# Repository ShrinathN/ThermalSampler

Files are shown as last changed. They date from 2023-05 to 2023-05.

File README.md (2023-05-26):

# ThermalSampler

Wireless thermal logger. Intended use is to help in thermally modelling a room.

Sensor nodes made using an STM32G0 MCU and connectivity options include

* nRF24L01+
* RFM95W/CW/TW
* RFM96W/TW

Sleep current is ~2uA

Aggregator is a simple ESP32 based dev board connected to nRF24L01+ (PA breakout board) in my case.

# Fully assembled

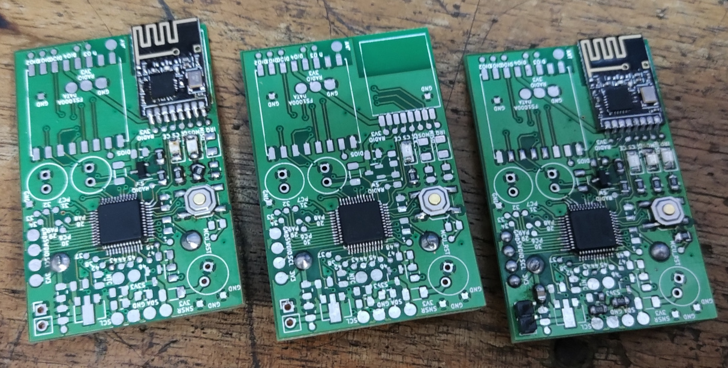
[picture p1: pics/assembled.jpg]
Assembled 1

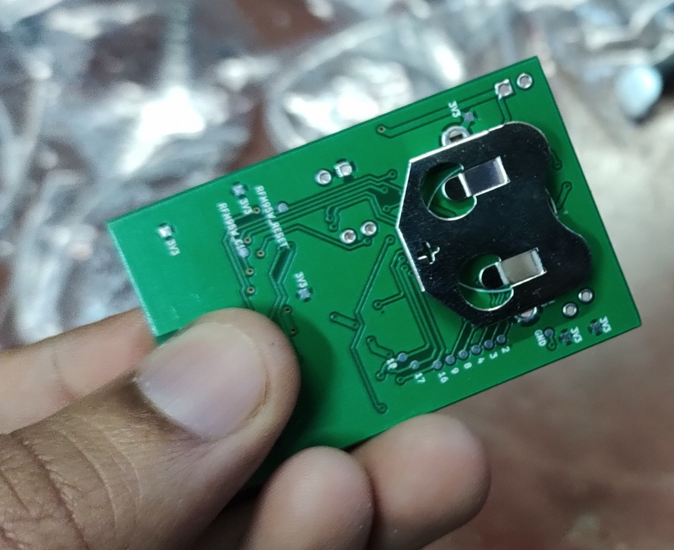
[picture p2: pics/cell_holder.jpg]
Assembled 2

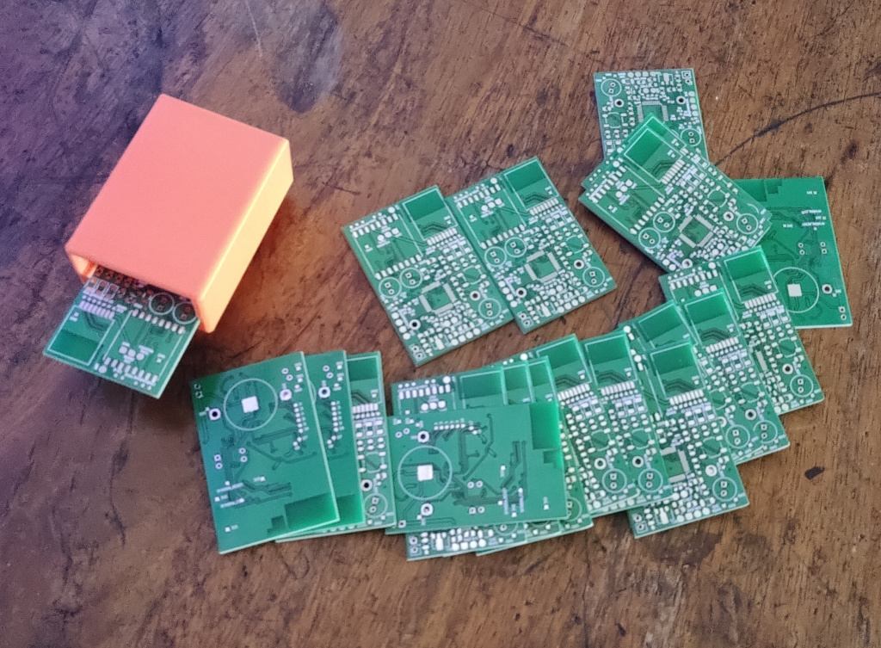
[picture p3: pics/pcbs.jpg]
Assembled 3

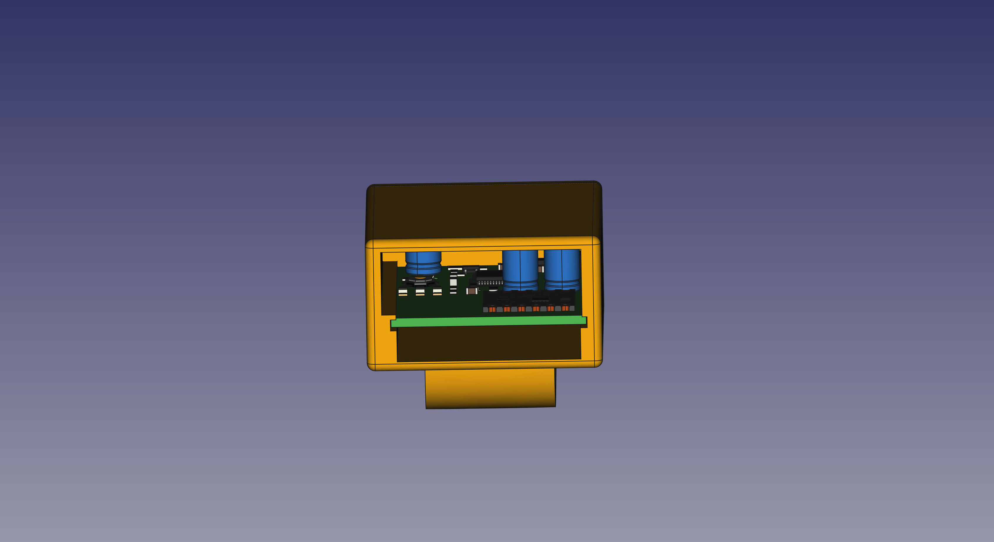
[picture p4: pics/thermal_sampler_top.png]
Assembled 4


# PCB

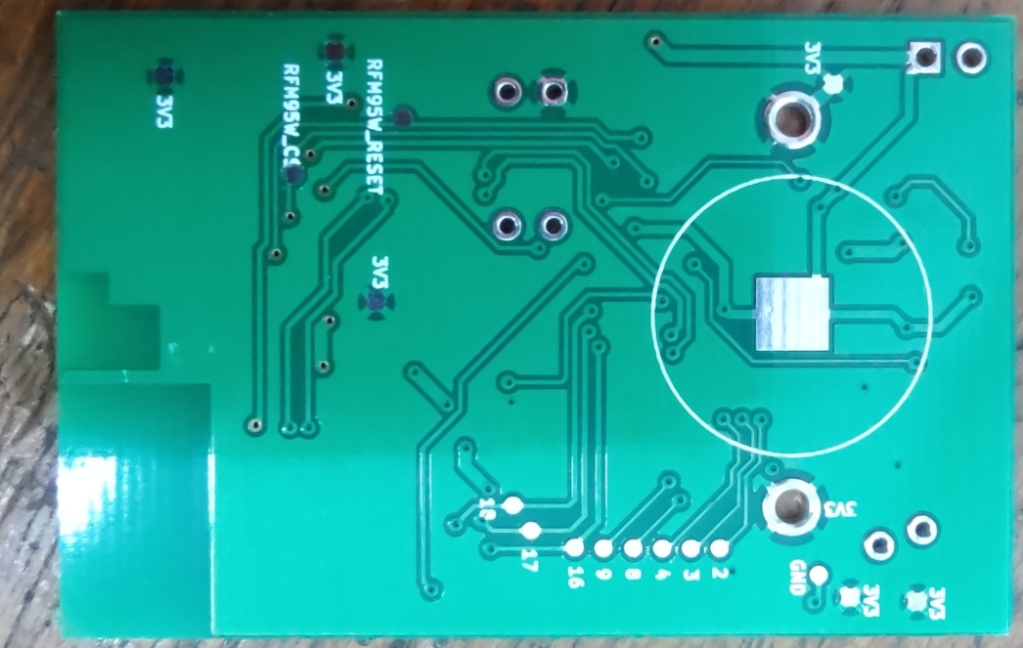
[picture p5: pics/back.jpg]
Front

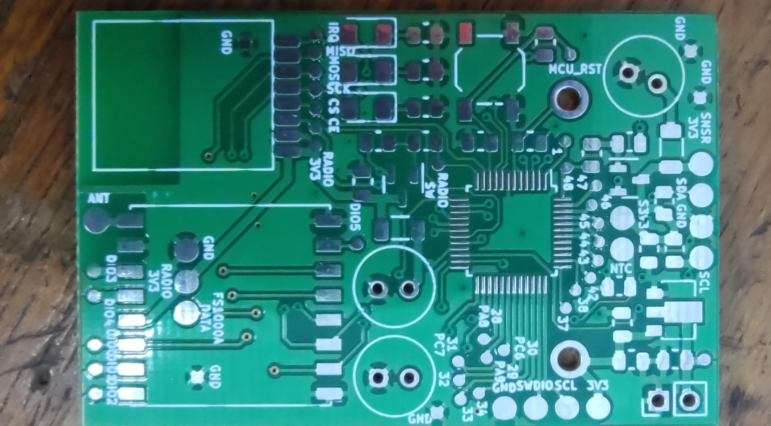
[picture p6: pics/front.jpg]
Back

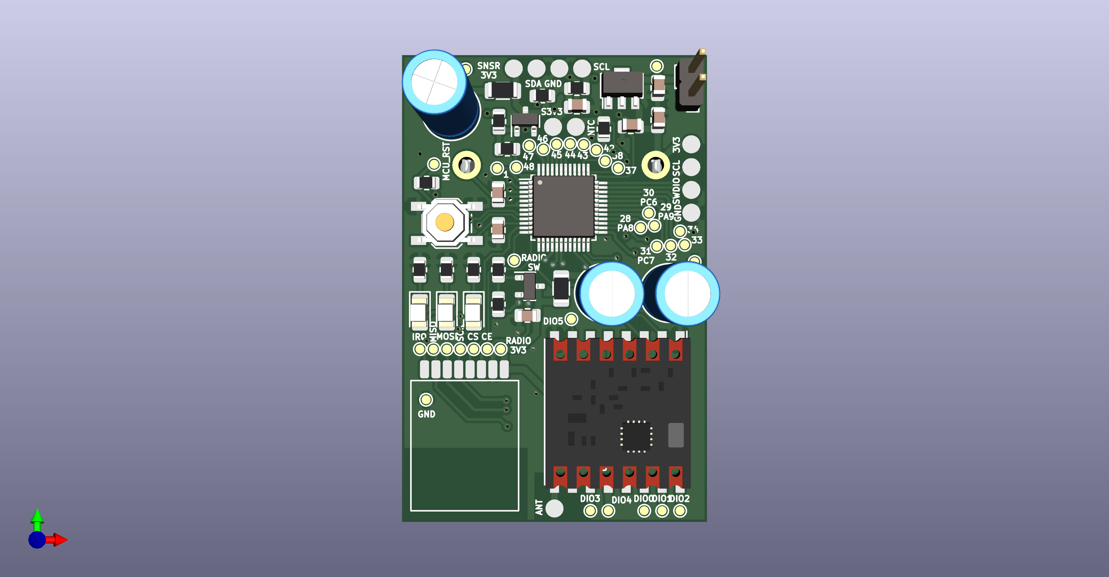
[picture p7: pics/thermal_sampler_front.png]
FrontRender

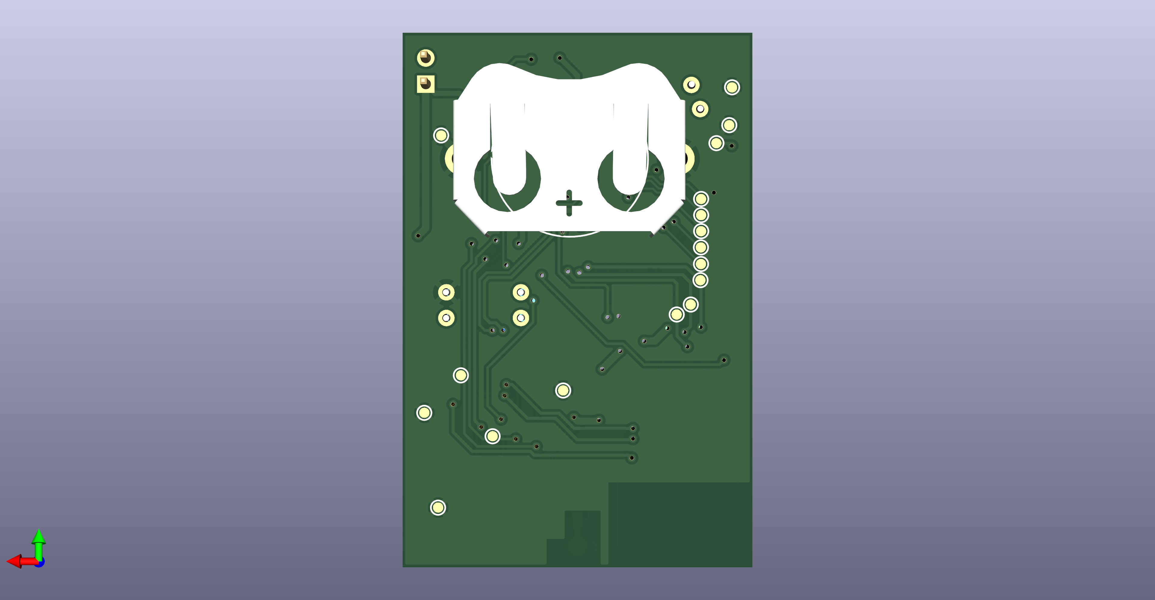
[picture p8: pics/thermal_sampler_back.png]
BackRender


# Enclosure

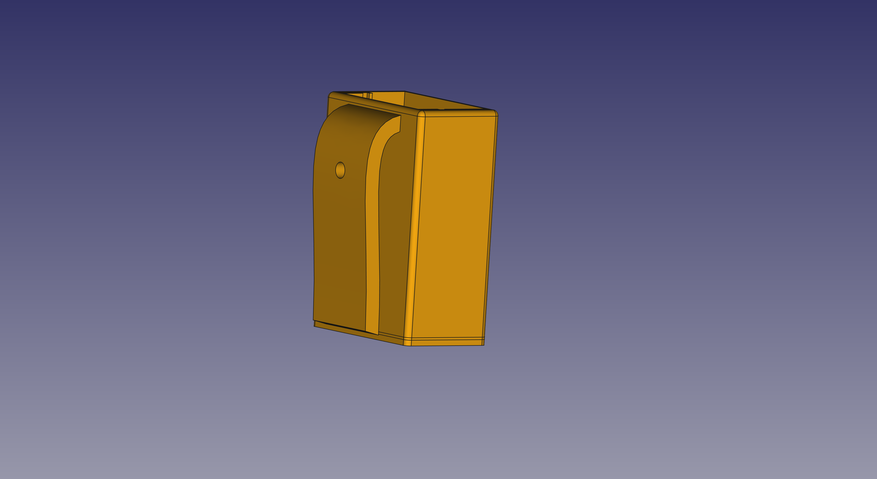
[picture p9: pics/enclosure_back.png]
Perspective 1

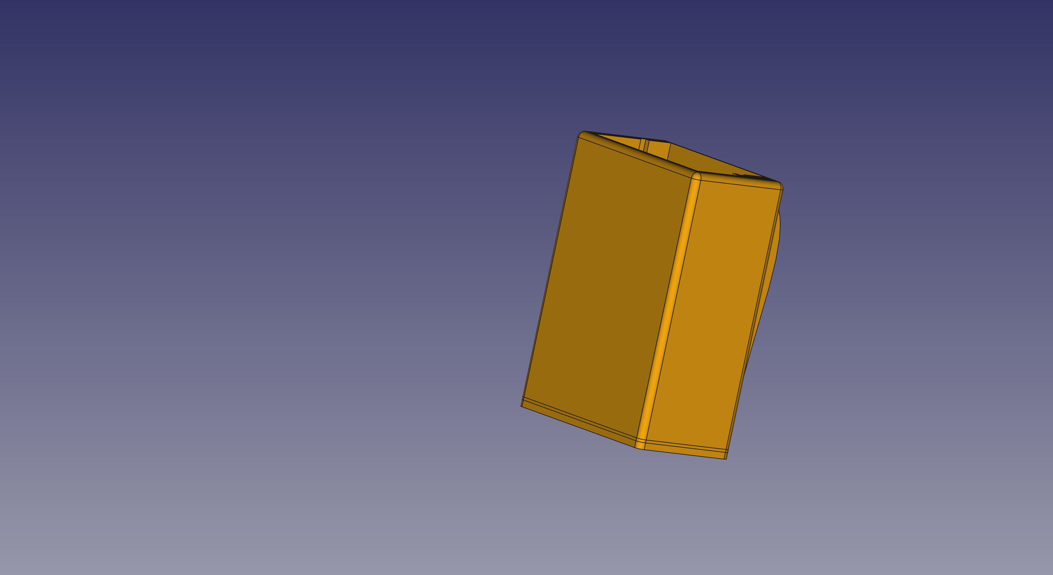
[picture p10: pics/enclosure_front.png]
Perspective 2

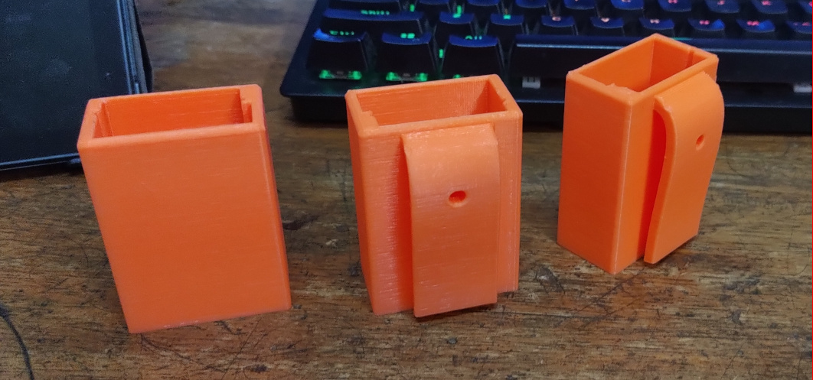
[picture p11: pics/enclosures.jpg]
Perspective 3


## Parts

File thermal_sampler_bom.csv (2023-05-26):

Item | Qty | Reference(s) | Value | LibPart | Footprint | Datasheet | For 5 boards
1 | 5 | C1, C2, C3, C7, C9 | 10uF | Device:C | Capacitor_SMD:C_0805_2012Metric | ~ | 25
2 | 3 | C4, C8, C10 | 220uF | Device:C | Capacitor_THT:C_Radial_D6.3mm_H11.0mm_P2.50mm | ~ | 15
3 | 2 | C5, C6 | 100nF | Device:C | Capacitor_SMD:C_0805_2012Metric | ~ | 10
4 | 3 | D1, D2, D3 | LED | Device:LED | LED_SMD:LED_1206_3216Metric | ~ | 15
5 | 1 | J1 | CR2032 | Connector_Generic:Conn_01x02 | CR2032_THT:CR2032_THT | ~ | 5
6 | 1 | J2 | power_connector | Connector_Generic:Conn_01x02 | Connector_PinHeader_2.54mm:PinHeader_1x02_P2.54mm_Vertical | ~ | 5
7 | 1 | J3 | swd_header | Connector_Generic:Conn_01x04 | smd_footprint:Conn_01x04 | ~ | 5
8 | 1 | J4 | RFM95W_Antenna | Connector_Generic:Conn_01x01 | smd_footprint:Conn_01x01 | ~ | 5
9 | 1 | J5 | FS1000A | Connector_Generic:Conn_01x03 | smd_footprint:Conn_01x03 | ~ | 5
10 | 1 | J6 | ZS05 | Connector_Generic:Conn_01x04 | smd_footprint:Conn_01x04 | ~ | 5
11 | 1 | J7 | thermistor_connector | Connector_Generic:Conn_01x02 | smd_footprint:Conn_01x02 | ~ | 5
12 | 2 | Q1, Q2 | CJ3401 | Device:Q_PMOS_GSD | Package_TO_SOT_SMD:SOT-23 | ~ | 10
13 | 3 | R1, R6, R11 | 1Meg | Device:R | Resistor_SMD:R_0805_2012Metric | ~ | 15
14 | 3 | R2, R3, R4 | 1k | Device:R | Resistor_SMD:R_0805_2012Metric | ~ | 15
15 | 2 | R5, R10 | 22R | Device:R | Resistor_SMD:R_0805_2012Metric | ~ | 10
16 | 2 | R7, R12 | 2R | Device:R | Resistor_SMD:R_1206_3216Metric | ~ | 10
17 | 2 | R8, R9 | 4k7 | Device:R | Resistor_SMD:R_0805_2012Metric | ~ | 10
18 | 1 | R13 | 100k | Device:R | Resistor_SMD:R_0805_2012Metric | ~ | 5
19 | 1 | SW1 | rst_switch | Switch:SW_Push | Button_Switch_SMD:SW_SPST_TL3342 | ~ | 5
20 | 1 | U1 | HT7333 | HT7333:HT7333 | Package_TO_SOT_SMD:SOT-89-3 | https://datasheet.lcsc.com/szlcsc/Holtek-Semicon-HT7333-A_C21583.pdf | 5
21 | 1 | U2 | STM32G030C8T6 | STM32G030C8T6:STM32G030C8T6 | Package_QFP:LQFP-48_7x7mm_P0.5mm |  | 5
22 | 1 | U3 | nRF24L01_SMD | nrf24l01_smd:nRF24L01_SMD | nRF24L01_SMD:nRF24L01_SMD |  | 5
23 | 1 | U4 | RFM95W-868S2 | RF_Module:RFM95W-868S2 | RF_Module:HOPERF_RFM9XW_SMD | https://www.hoperf.com/data/upload/portal/20181127/5bfcbea20e9ef.pdf | 5

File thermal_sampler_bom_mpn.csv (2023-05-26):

S.No | Quantity | Designator | Description (VALUE) | Manufacturing Part No
1 | 5 | C1, C2, C3, C7, C9 | 10uF | CL21A106KPFNNNE
2 | 3 | C4, C8, C10 | 220uF | UWT1H221MNL1GS
3 | 2 | C5, C6 | 100nF | 0805B104K500NT
4 | 3 | D1, D2, D3 | LED | SZYY1206R
5 | 1 | J1 | CR2032 | MY-2032-08
6 | 1 | J2 | power_connector | RE-H022TD-1190(LF)(SN)
7 | 1 | J6 | ZS05 | DHT11
8 | 2 | Q1, Q2 | CJ3401 | CJ3401
9 | 3 | R1, R6, R11 | 1Meg | 0805W8F1004T5E
10 | 3 | R2, R3, R4 | 1k | RC0805FR-071KL
11 | 2 | R5, R10 | 22R | RC0805FR-0722RL
12 | 2 | R7, R12 | 2R | FRC0805J2R0TS
13 | 2 | R8, R9 | 4k7 | RS-05K472JT
14 | 1 | R13 | 100k | 0805W8F1003T5E
15 | 1 | SW1 | rst_switch | TS-1187A-B-A-B
16 | 1 | U1 | HT7333 | HT7333-A
17 | 1 | U2 | STM32G030C8T6 | STM32G030C8T6
18 | 1 | U4 | RFM95W-868S2 | DL-RFM95-868M

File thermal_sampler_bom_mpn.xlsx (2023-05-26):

S.No | Quantity | Designator | Description (VALUE) | Manufacturing Part No
1 | 5 | C1, C2, C3, C7, C9 | 10uF | C0805C106K8PAC7800
2 | 3 | C4, C8, C10 | 220uF | RL81C221MDN1KX
3 | 2 | C5, C6 | 100nF | 0805B104K101CC
4 | 3 | D1, D2, D3 | LED | LTST-C150KGKT
5 | 1 | J1 | CR2032 | 3035
6 | 1 | J2 | power_connector | 68000-102HLF
7 | 1 | J6 | ZS05 | 1528-5183-ND
8 | 2 | Q1, Q2 | CJ3401 | SSM3J328R,LF
9 | 3 | R1, R6, R11 | 1Meg | RC0805FR-071ML
10 | 3 | R2, R3, R4 | 1k | RC0805FR-071KL
11 | 2 | R5, R10 | 22R | RMCF0805JT22R0
12 | 2 | R7, R12 | 2R | RC0805FR-072RL
13 | 2 | R8, R9 | 4k7 | RMCF0805JT4K70
14 | 1 | R13 | 100k | RC0805FR-07100KL
15 | 1 | SW1 | rst_switch | PTS526 SK15 SMTR2 LFS
16 | 1 | U1 | HT7333 | HT7333-A
17 | 1 | U2 | STM32G030C8T6 | STM32G030C8T6
18 | 1 | U4 | RFM95W-868S2 | RFM95W-868S2

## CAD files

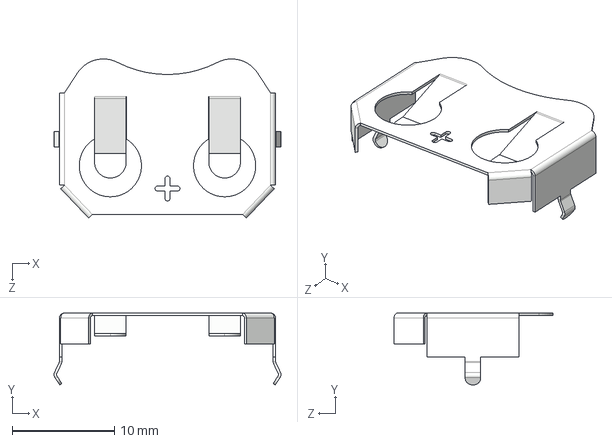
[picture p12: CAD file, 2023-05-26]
Custom Parts/3D Models/keystone-PN3035.STEP
22.2 x 7.04 x 15.6 mm

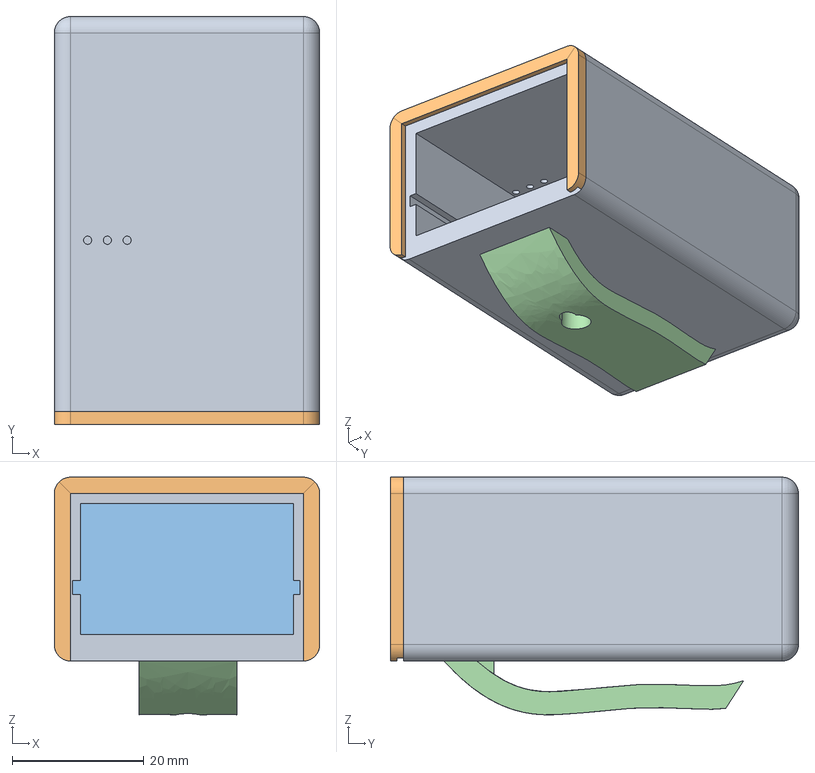
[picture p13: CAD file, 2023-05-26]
Enclosures/closed/Unnamed-Enclosure12.step
40.3 x 62.0 x 36.1 mm
MainBody
Top Rail
Back Close
Clip

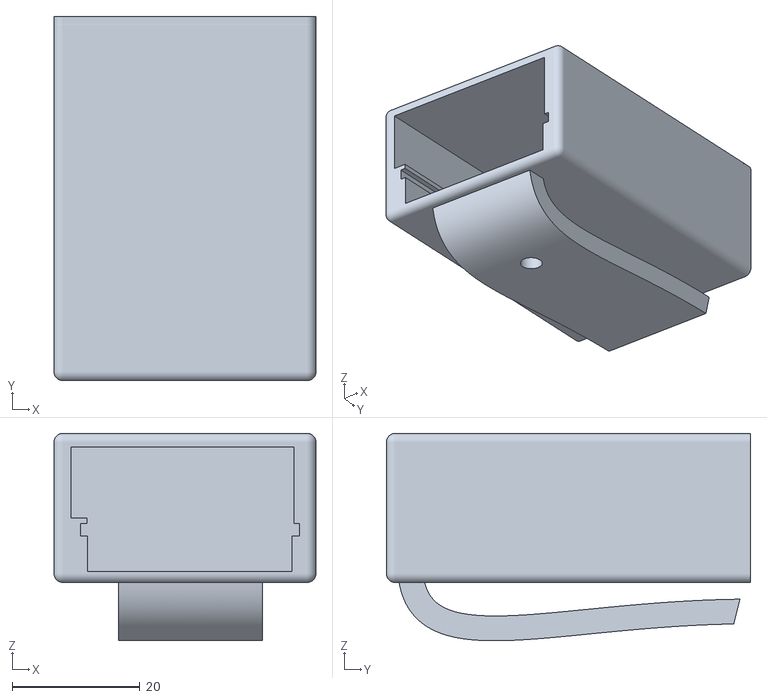
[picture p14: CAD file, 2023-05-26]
Enclosures/open_top/dabba2.stl
41.0 x 57.0 x 32.5

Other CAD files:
Enclosures/closed/dabba-Enclosure.step
Enclosures/open_top/dabba.FCStd
Enclosures/closed/enclosure_closed.stl
Enclosures/closed/dabba.FCStd
Enclosures/closed/Unnamed-Enclosure132.step
Enclosures/closed/Unnamed-Enclosure1.step
Enclosures/closed/Unnamed-Enclosure1.stl
Enclosures/open_top/dabba.stl

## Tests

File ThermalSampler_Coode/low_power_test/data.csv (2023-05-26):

 | id | temp | hum
0 | 0 | 30 | 27
1 | 1 | 30 | 27
2 | 2 | 30 | 27
3 | 3 | 30 | 27
4 | 4 | 30 | 27
5 | 5 | 30 | 27
6 | 6 | 30 | 27
7 | 7 | 30 | 27
8 | 8 | 30 | 27
9 | 9 | 30 | 27
10 | 10 | 30 | 27
11 | 11 | 30 | 27
12 | 12 | 30 | 27
13 | 13 | 30 | 27
14 | 14 | 30 | 27
15 | 15 | 30 | 27
16 | 16 | 30 | 27
17 | 17 | 30 | 27
18 | 18 | 30 | 27
19 | 19 | 30 | 27
20 | 20 | 30 | 28
21 | 21 | 30 | 28
22 | 22 | 30 | 28
23 | 23 | 30 | 28
24 | 24 | 30 | 28
25 | 25 | 30 | 28
26 | 26 | 29 | 28
27 | 27 | 30 | 29
28 | 28 | 29 | 29
29 | 29 | 29 | 29
30 | 30 | 29 | 29
31 | 31 | 29 | 29
32 | 32 | 29 | 29
33 | 33 | 29 | 30
34 | 34 | 29 | 30
35 | 35 | 29 | 30
36 | 36 | 29 | 30
37 | 37 | 29 | 31
38 | 38 | 29 | 31
39 | 39 | 29 | 31
40 | 40 | 29 | 32
41 | 41 | 29 | 32
42 | 42 | 29 | 32
43 | 43 | 29 | 33
44 | 44 | 29 | 33
45 | 45 | 29 | 33
46 | 46 | 29 | 33
47 | 47 | 29 | 34
48 | 48 | 29 | 34
49 | 49 | 29 | 34
50 | 50 | 28 | 35
51 | 51 | 28 | 35
52 | 52 | 29 | 35
53 | 53 | 28 | 35
54 | 54 | 28 | 36
55 | 55 | 28 | 36
56 | 56 | 28 | 36
57 | 57 | 28 | 37
58 | 58 | 28 | 37
59 | 59 | 28 | 37
60 | 60 | 28 | 38
61 | 61 | 28 | 38
62 | 62 | 28 | 38
63 | 63 | 28 | 38
64 | 64 | 28 | 39
65 | 65 | 28 | 39
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

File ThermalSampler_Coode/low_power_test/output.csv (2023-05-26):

 | id | temperature | humidity
0 | 230 | 30 | 27
1 | 231 | 30 | 27
2 | 232 | 30 | 27
3 | 0 | 30 | 27
4 | 1 | 30 | 27
5 | 2 | 30 | 27
6 | 3 | 30 | 27
7 | 4 | 30 | 27
8 | 5 | 30 | 27
9 | 6 | 30 | 27
10 | 7 | 30 | 27
11 | 8 | 30 | 27
12 | 9 | 30 | 27
13 | 10 | 30 | 27
14 | 11 | 30 | 27
15 | 12 | 30 | 27
16 | 13 | 30 | 27
17 | 14 | 30 | 27
18 | 15 | 30 | 27
19 | 16 | 30 | 27
20 | 17 | 30 | 27
21 | 18 | 30 | 27
22 | 19 | 30 | 27
23 | 20 | 30 | 28
24 | 21 | 30 | 28
25 | 22 | 30 | 28
26 | 23 | 30 | 28
27 | 24 | 30 | 28
28 | 25 | 30 | 28
29 | 26 | 29 | 28
30 | 27 | 30 | 29
31 | 28 | 29 | 29
32 | 29 | 29 | 29
33 | 30 | 29 | 29
34 | 31 | 29 | 29
35 | 32 | 29 | 29
36 | 33 | 29 | 30
37 | 34 | 29 | 30
38 | 35 | 29 | 30
39 | 36 | 29 | 30
40 | 37 | 29 | 31
41 | 38 | 29 | 31
42 | 39 | 29 | 31
43 | 40 | 29 | 32
44 | 41 | 29 | 32
45 | 42 | 29 | 32
46 | 43 | 29 | 33
47 | 44 | 29 | 33
48 | 45 | 29 | 33
49 | 46 | 29 | 33
50 | 47 | 29 | 34
51 | 48 | 29 | 34
52 | 49 | 29 | 34
53 | 50 | 28 | 35
54 | 51 | 28 | 35
55 | 52 | 29 | 35
56 | 53 | 28 | 35
57 | 54 | 28 | 36
58 | 55 | 28 | 36
59 | 56 | 28 | 36
60 | 57 | 28 | 37
61 | 58 | 28 | 37
62 | 59 | 28 | 37
63 | 60 | 28 | 38
64 | 61 | 28 | 38
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

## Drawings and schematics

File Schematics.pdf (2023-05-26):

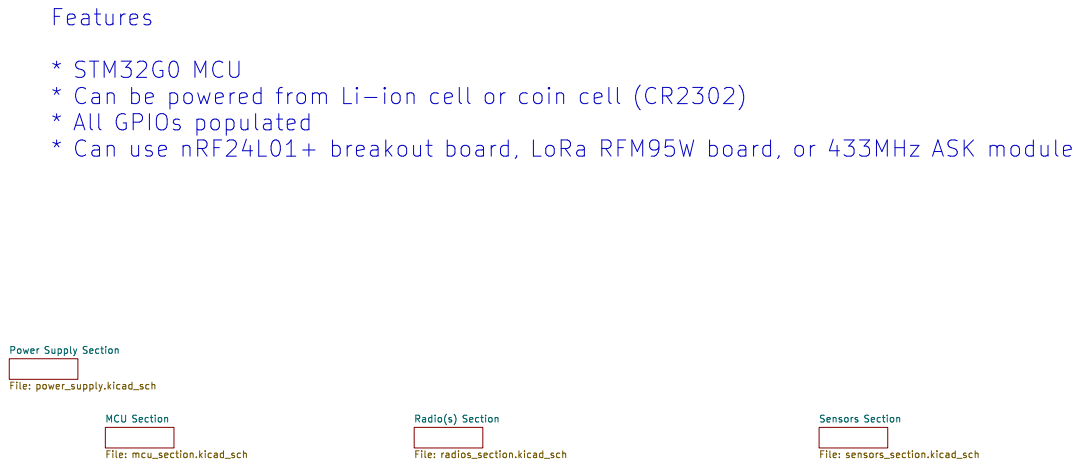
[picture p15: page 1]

Sensors Section File: sensors_section.kicad_sch Radio(s) Section File: radios_section.kicad_sch MCU Section File: mcu_section.kicad_sch Power Supply Section File: power_supply.kicad_sch

Id: 1/5 Title: File: thermal_sampler.kicad_sch Sheet: /

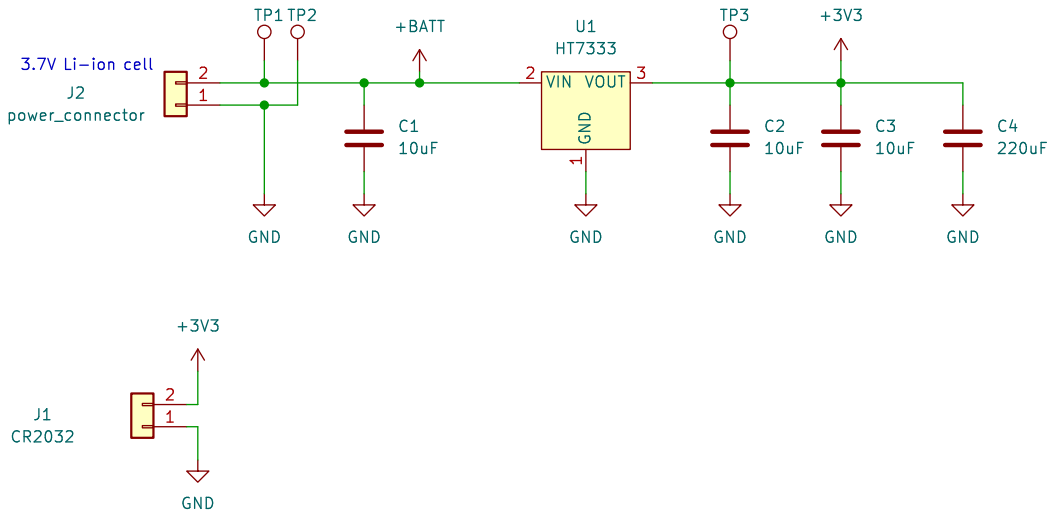
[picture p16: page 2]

Id: 2/5 Title: File: power_supply.kicad_sch Sheet: /Power Supply Section/

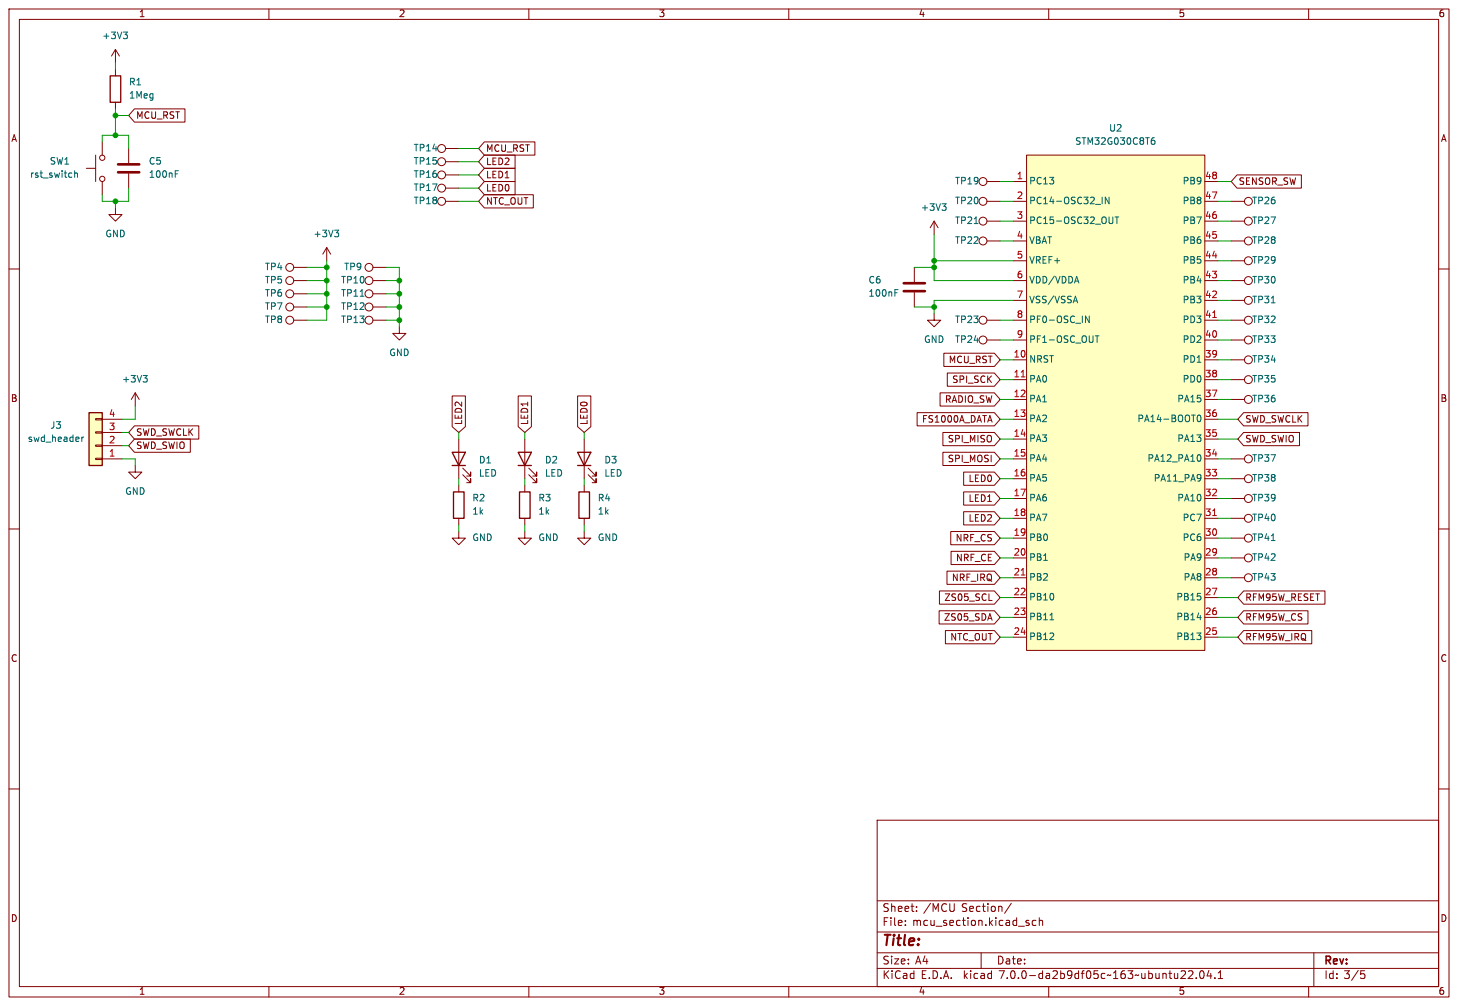
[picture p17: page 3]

Id: 3/5 Title: File: mcu_section.kicad_sch Sheet: /MCU Section/ GND

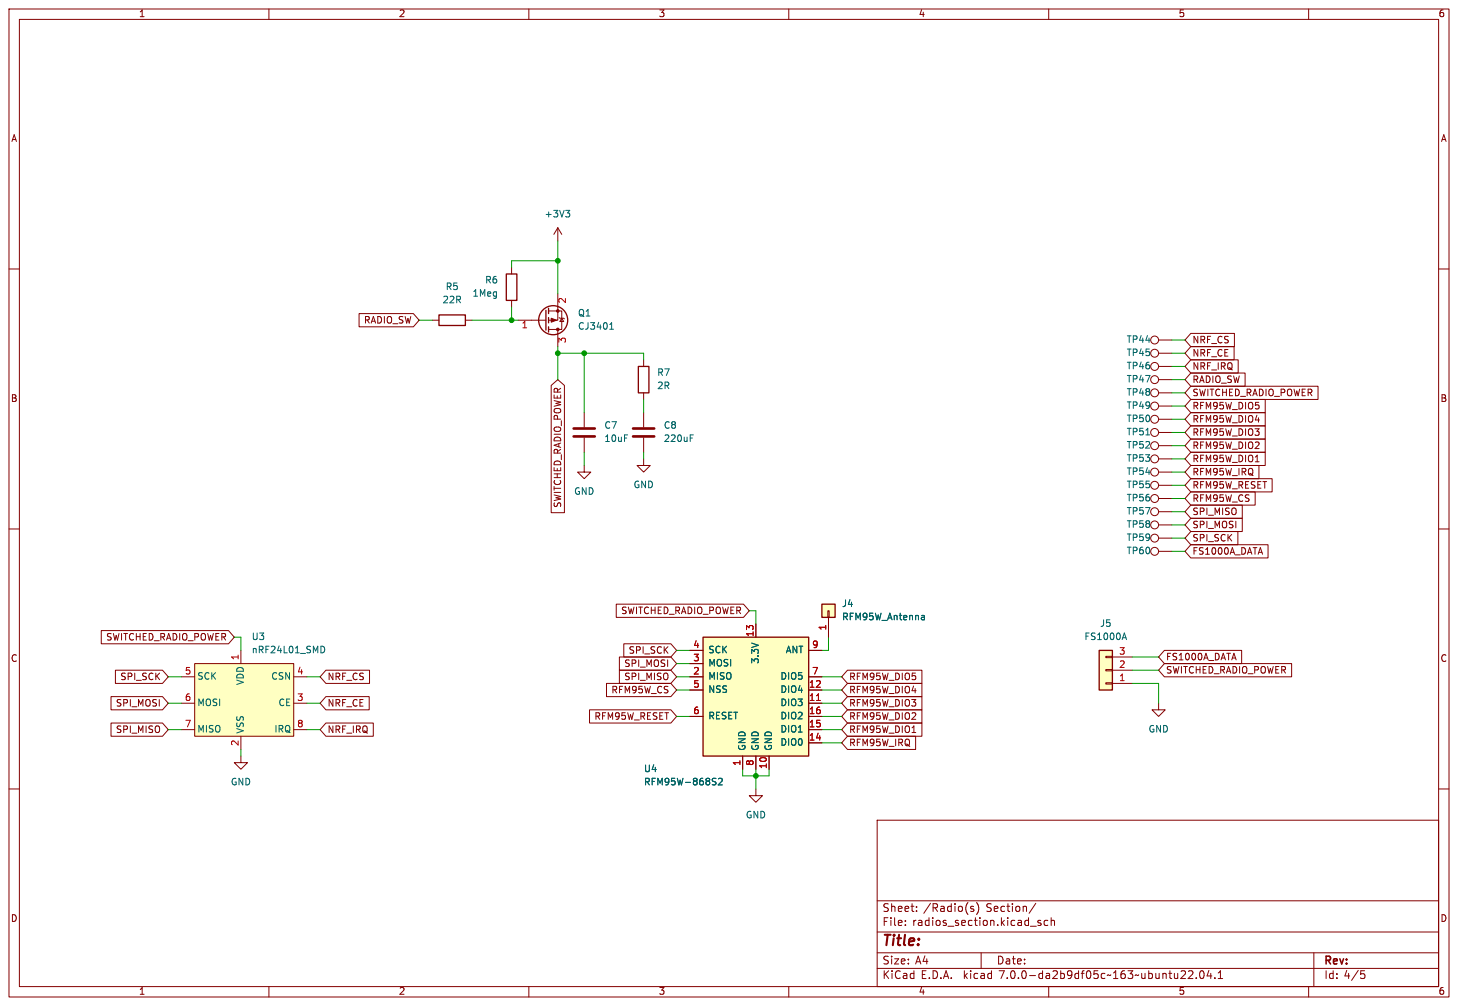
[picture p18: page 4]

1 GND 10 DIO3 11 DIO4 12 3.3V 13 DIO0 14 DIO1 15 DIO2 16 MISO 2 MOSI 3 SCK 4 NSS 5 RESET 6 DIO5 7 GND

2 CE 3 CSN 4 SCK 5 MOSI 6 MISO 7

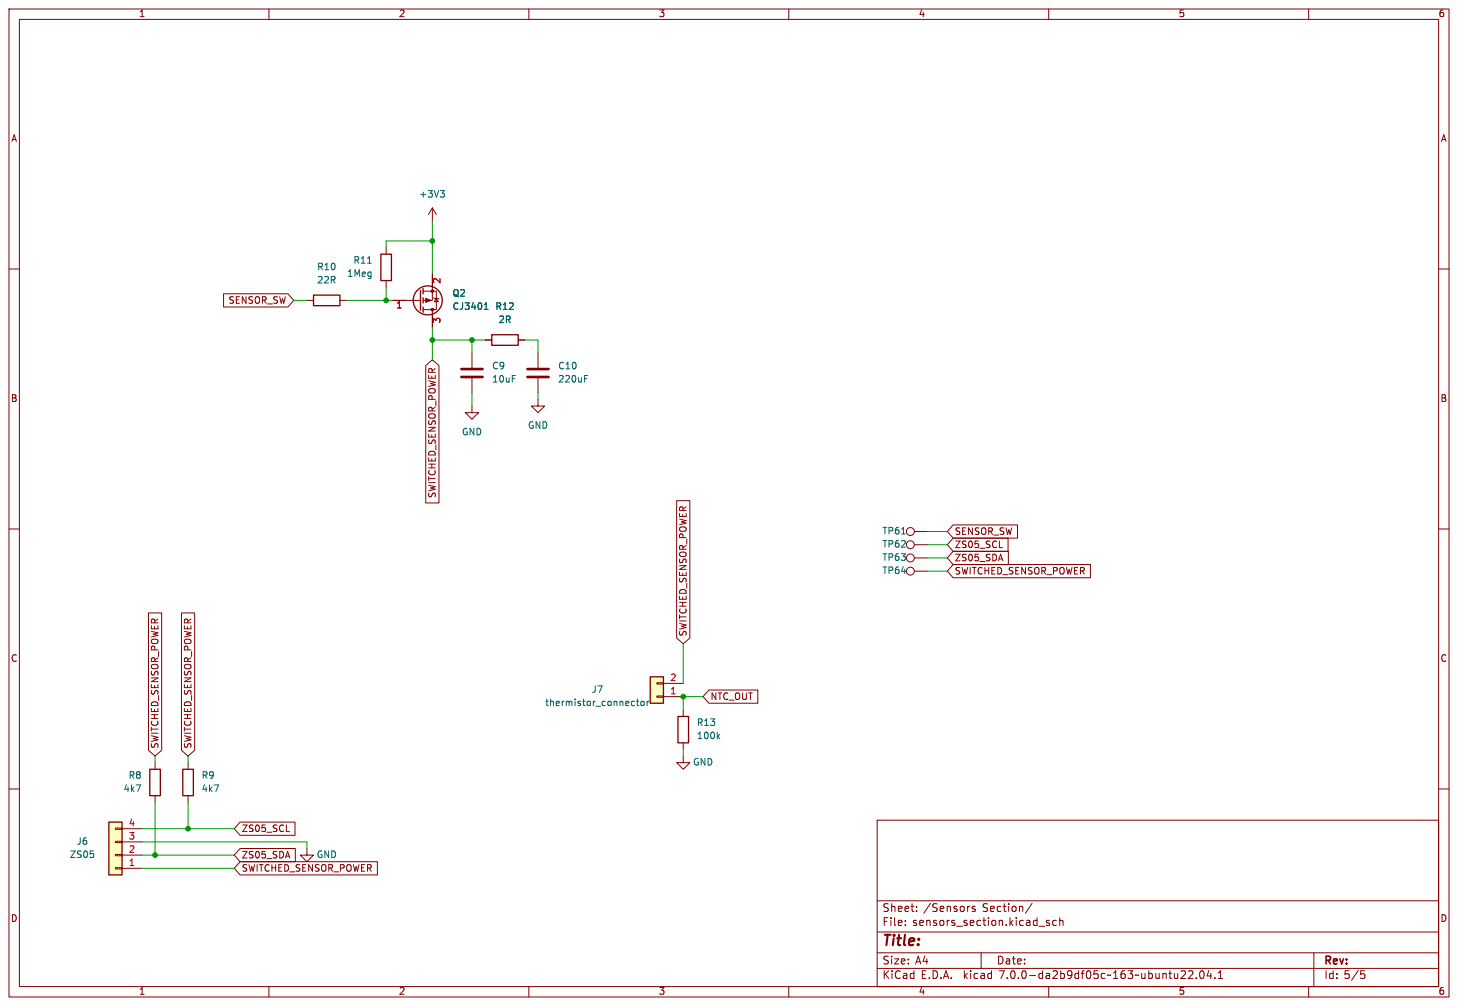
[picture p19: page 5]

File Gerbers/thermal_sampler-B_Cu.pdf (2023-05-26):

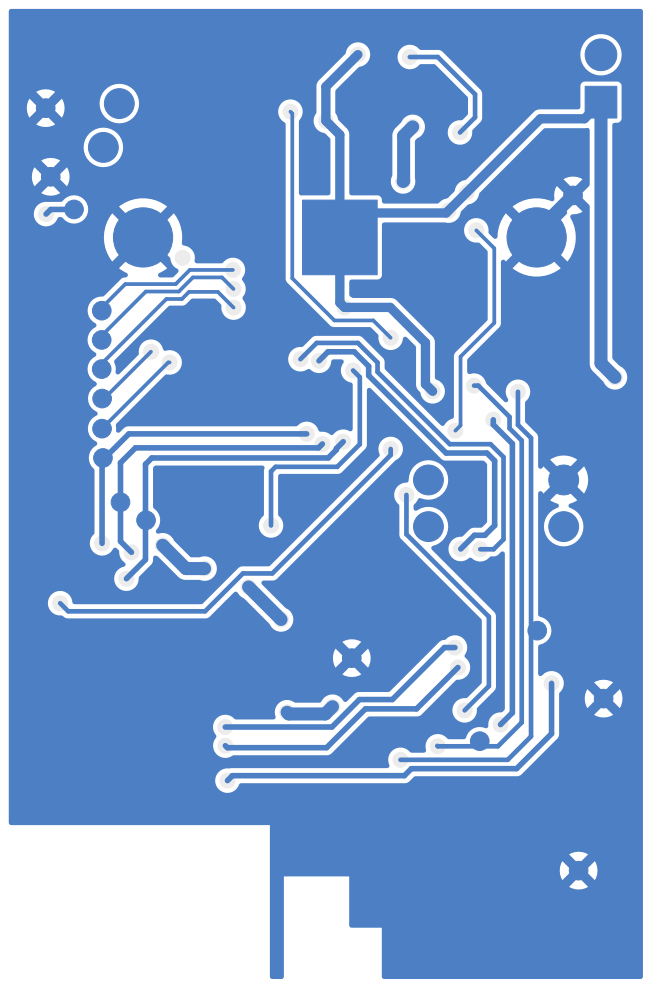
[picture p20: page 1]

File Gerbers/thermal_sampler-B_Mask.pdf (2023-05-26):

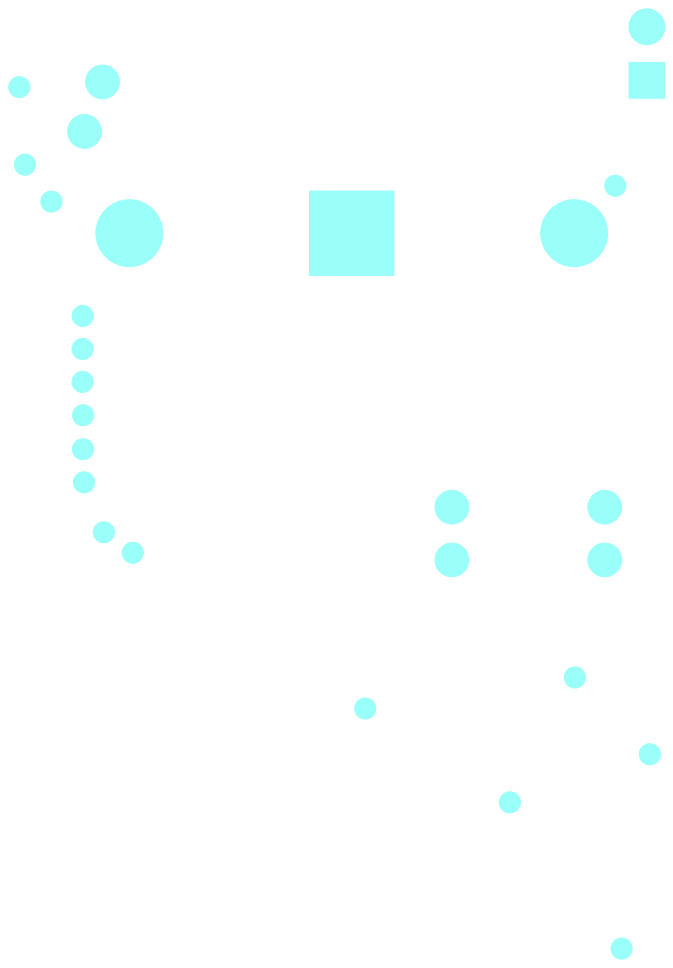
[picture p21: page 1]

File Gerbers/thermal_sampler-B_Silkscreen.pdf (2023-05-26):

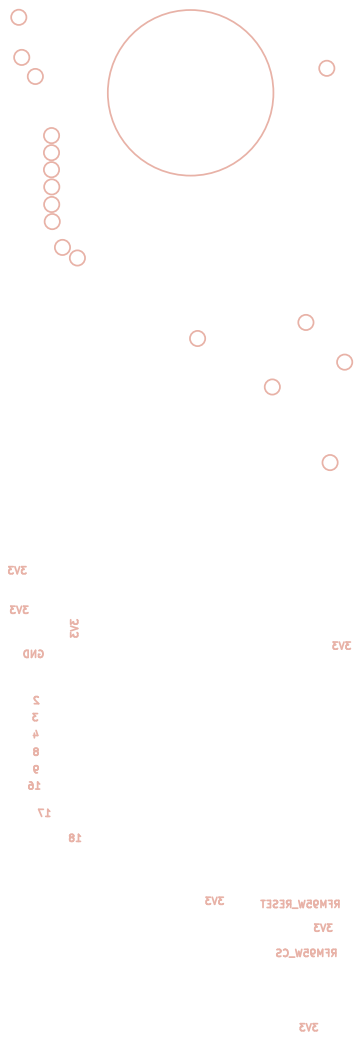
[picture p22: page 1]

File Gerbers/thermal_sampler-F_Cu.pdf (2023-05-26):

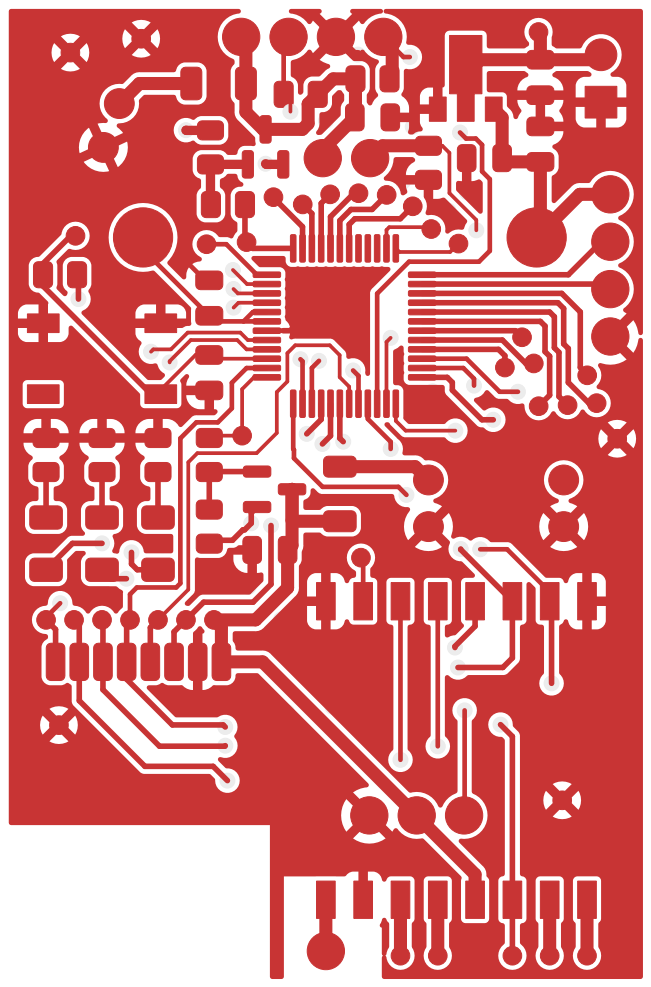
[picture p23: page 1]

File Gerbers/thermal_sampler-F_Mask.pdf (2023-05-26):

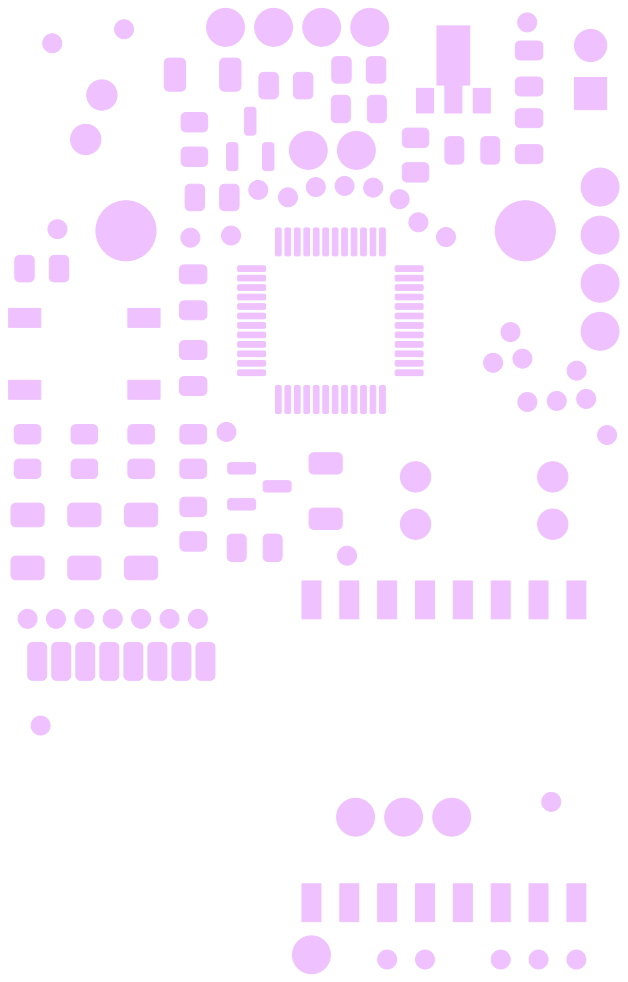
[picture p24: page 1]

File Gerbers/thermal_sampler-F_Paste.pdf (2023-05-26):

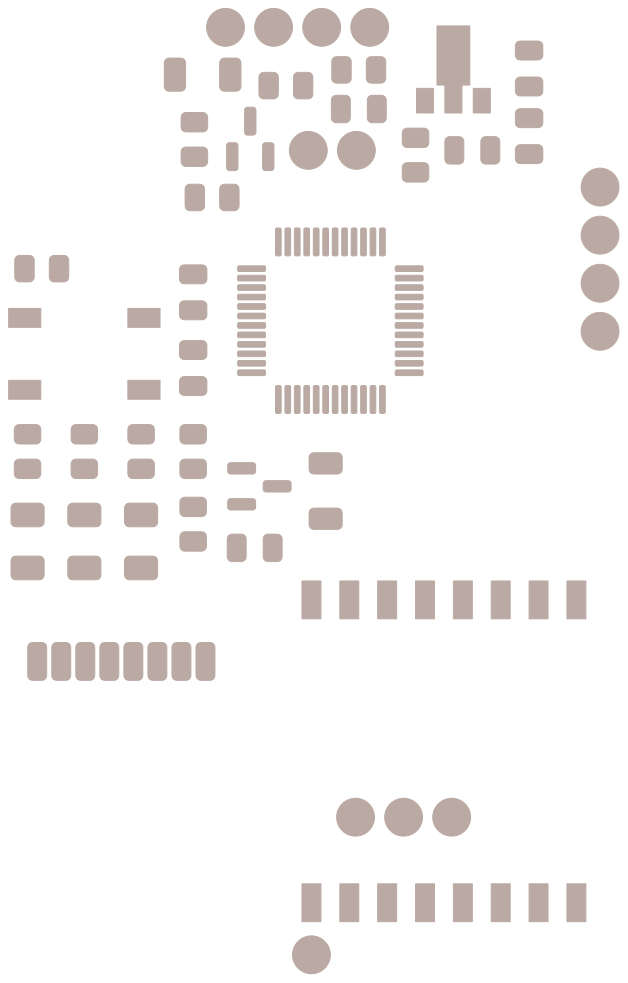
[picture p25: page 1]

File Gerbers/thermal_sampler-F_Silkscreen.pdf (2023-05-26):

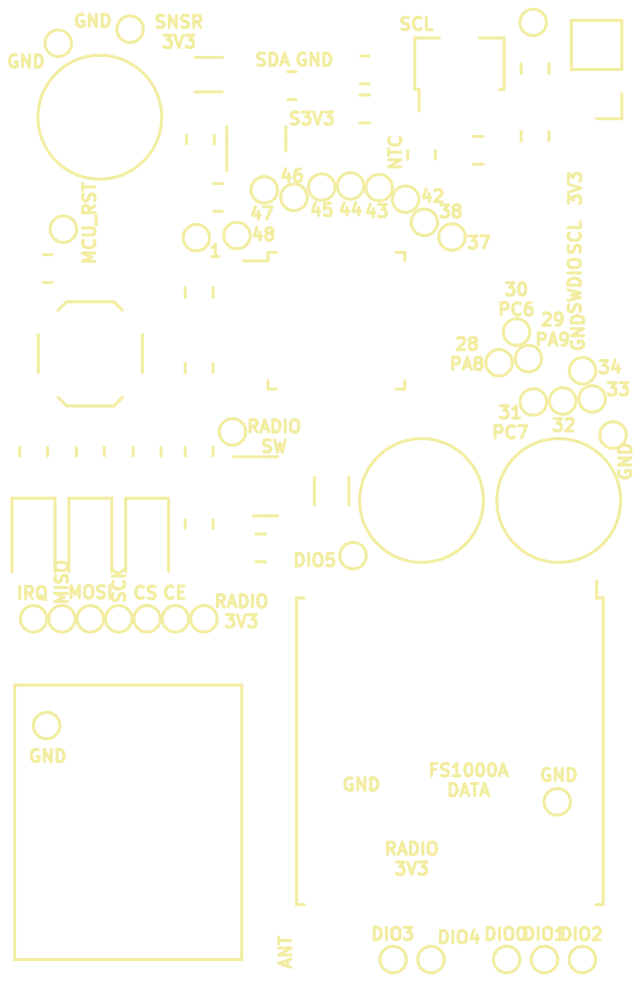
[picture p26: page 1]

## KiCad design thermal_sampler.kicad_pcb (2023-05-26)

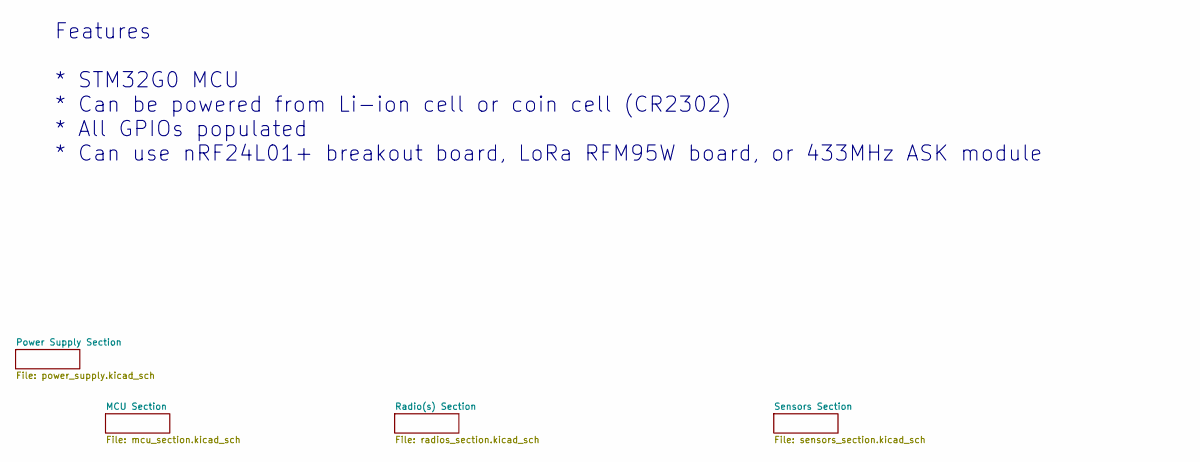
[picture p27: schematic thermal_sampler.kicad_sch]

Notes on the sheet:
Features * STM32G0 MCU * Can be powered from Li-ion cell or coin cell (CR2302) * All GPIOs populated * Can use nRF24L01+ breakout board, LoRa RFM95W board, or 433MHz ASK module

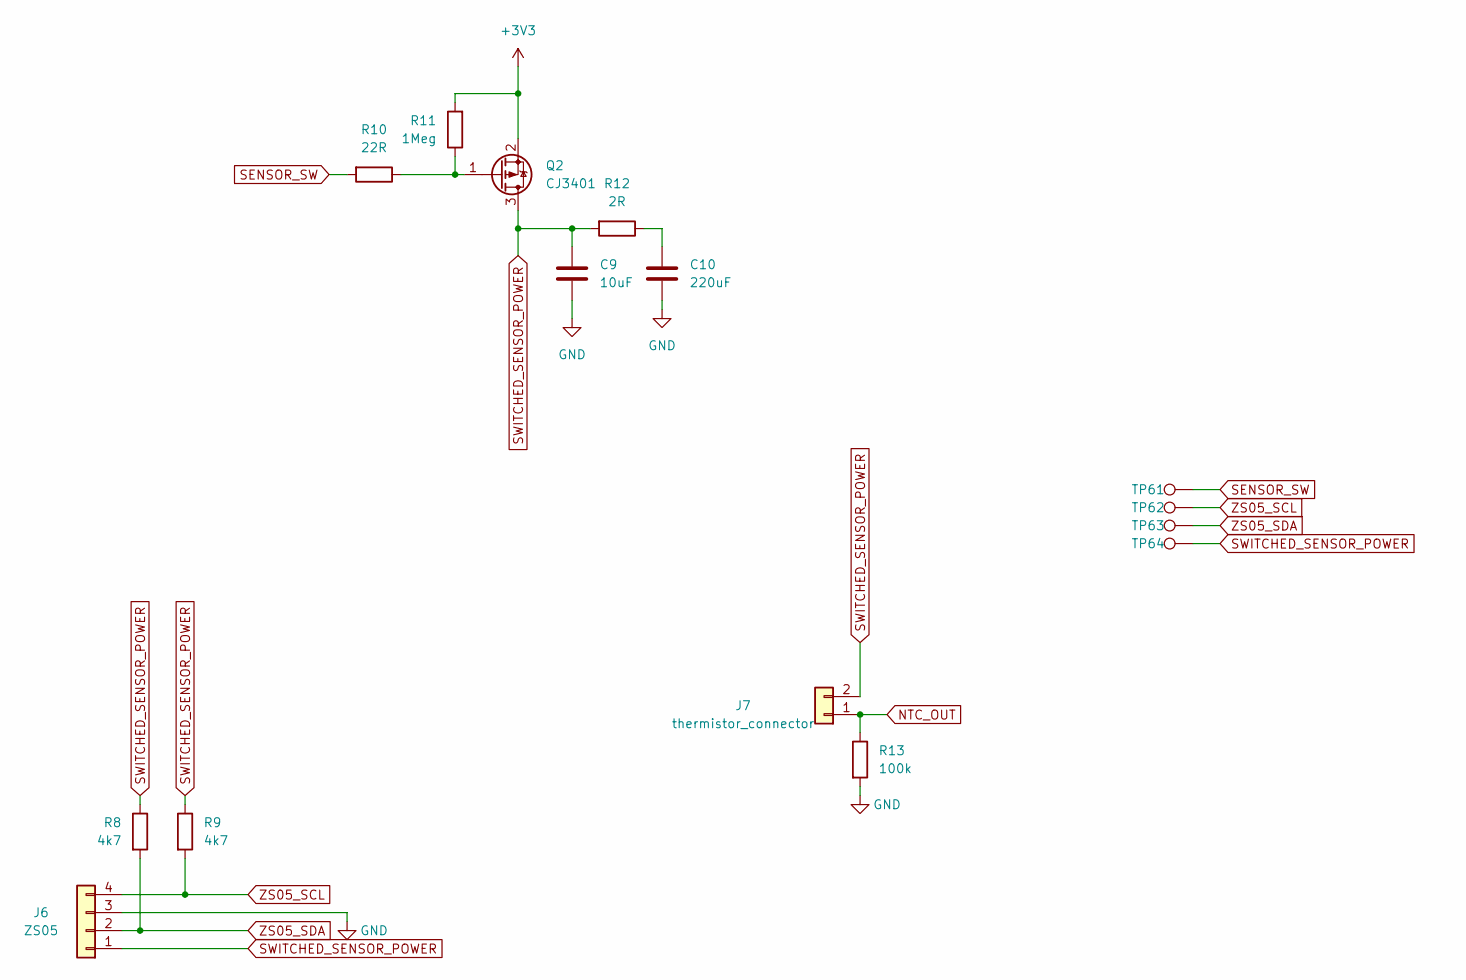
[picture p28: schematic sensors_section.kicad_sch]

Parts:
C9: 10uF; C_0805_2012Metric
C10: 220uF; C_Radial_D6.3mm_H11.0mm_P2.50mm
J6: ZS05; Conn_01x04
J7: thermistor_connector; Conn_01x02
Q2: CJ3401; SOT-23
R8, R9: 4k7; R_0805_2012Metric
R10: 22R; R_0805_2012Metric
R11: 1Meg; R_0805_2012Metric
R12: 2R; R_1206_3216Metric
R13: 100k; R_0805_2012Metric
TP61, TP62, TP63, TP64: TestPoint; TestPoint_Pad_D1.0mm

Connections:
+3V3: Q2.2 (S), R11.2; also elsewhere on the board
GND: C9.2, C10.2, J6.3, R13.2; also elsewhere on the board
NTC_OUT: J7.1, R13.1; also elsewhere on the board
unnamed: C10.1, R12.1
unnamed: Q2.1 (G), R10.1, R11.1
SENSOR_SW: R10.2, TP61.1; also elsewhere on the board
SWITCHED_SENSOR_POWER: C9.1, J6.1, J7.2, Q2.3 (D), R8.1, R9.1, R12.2, TP64.1
ZS05_SCL: J6.4, R9.2, TP62.1; also elsewhere on the board
ZS05_SDA: J6.2, R8.2, TP63.1; also elsewhere on the board

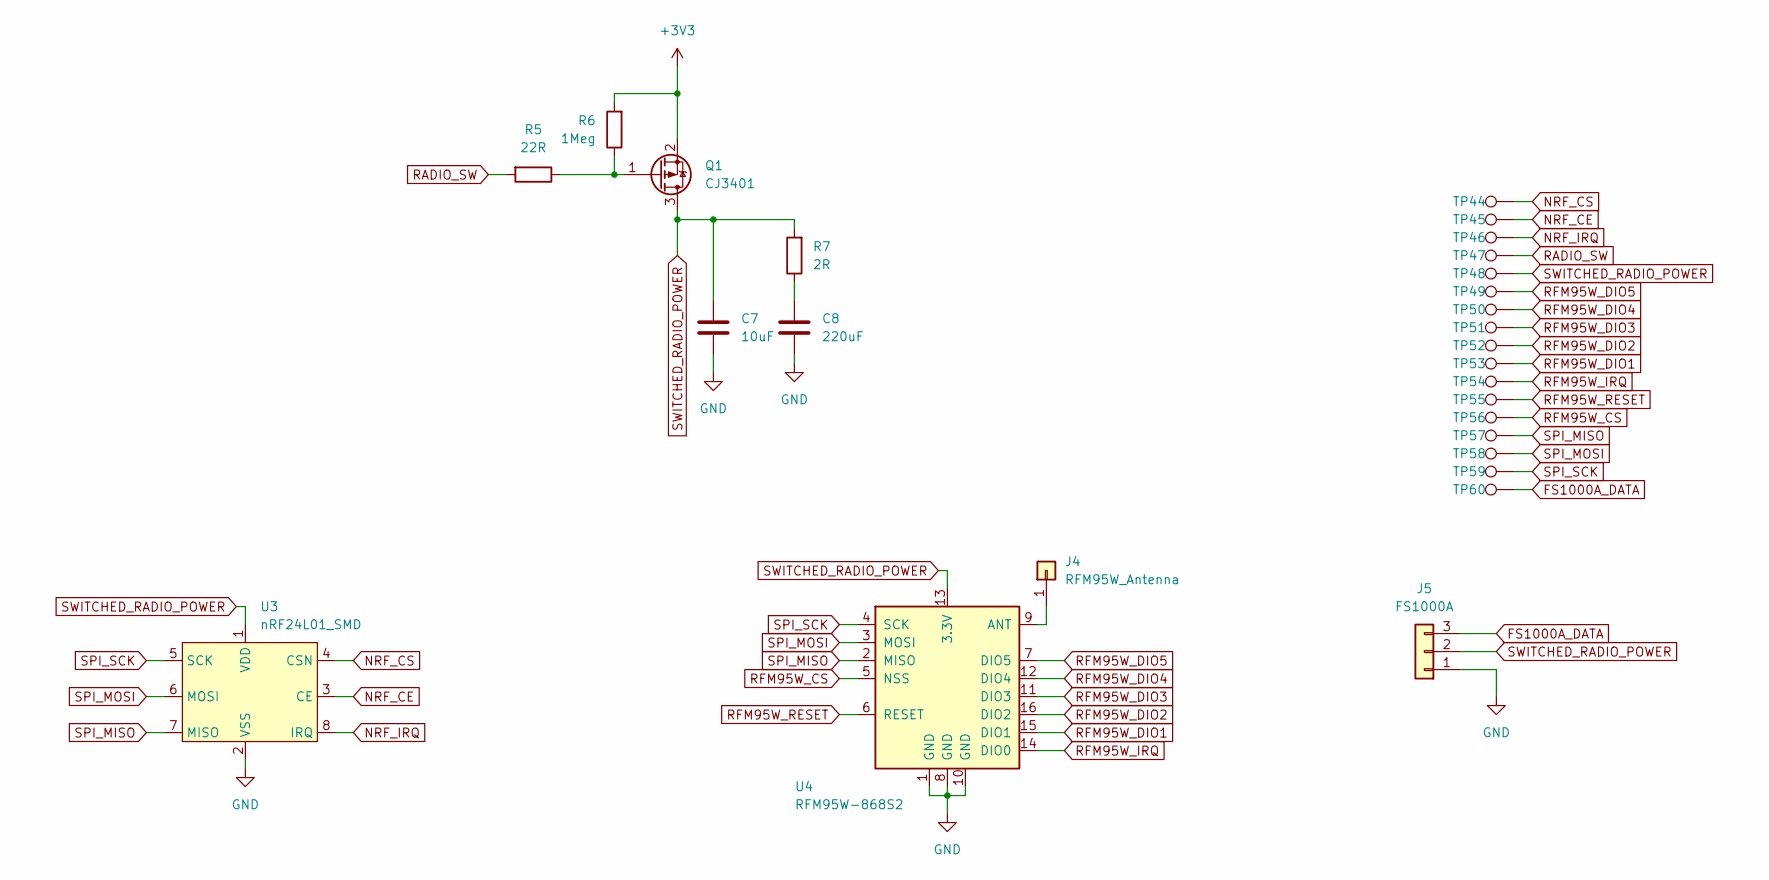
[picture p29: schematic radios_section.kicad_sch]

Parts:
C7: 10uF; C_0805_2012Metric
C8: 220uF; C_Radial_D6.3mm_H11.0mm_P2.50mm
J4: RFM95W_Antenna; Conn_01x01
J5: FS1000A; Conn_01x03
Q1: CJ3401; SOT-23
R5: 22R; R_0805_2012Metric
R6: 1Meg; R_0805_2012Metric
R7: 2R; R_1206_3216Metric
TP44, TP45, TP46, TP47, TP48, TP49, TP50, TP51, TP52, TP53, TP54, TP55, TP56, TP57, TP58, TP59, TP60: TestPoint; TestPoint_Pad_D1.0mm
U3: nRF24L01_SMD
U4: RFM95W-868S2; HOPERF_RFM9XW_SMD

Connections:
+3V3: Q1.2 (S), R6.2; also elsewhere on the board
FS1000A_DATA: J5.3, TP60.1; also elsewhere on the board
GND: C7.2, C8.2, J5.1, U3.2 (VSS), U4.1 (GND), U4.8 (GND), U4.10 (GND); also elsewhere on the board
NRF_CE: TP45.1, U3.3 (CE); also elsewhere on the board
NRF_CS: TP44.1, U3.4 (CSN); also elsewhere on the board
NRF_IRQ: TP46.1, U3.8 (IRQ); also elsewhere on the board
unnamed: C8.1, R7.1
unnamed: J4.1, U4.9 (ANT)
unnamed: Q1.1 (G), R5.1, R6.1
RADIO_SW: R5.2, TP47.1; also elsewhere on the board
RFM95W_CS: TP56.1, U4.5 (NSS); also elsewhere on the board
RFM95W_DIO1: TP53.1, U4.15 (DIO1)
RFM95W_DIO2: TP52.1, U4.16 (DIO2)
RFM95W_DIO3: TP51.1, U4.11 (DIO3)
RFM95W_DIO4: TP50.1, U4.12 (DIO4)
RFM95W_DIO5: TP49.1, U4.7 (DIO5)
RFM95W_IRQ: TP54.1, U4.14 (DIO0); also elsewhere on the board
RFM95W_RESET: TP55.1, U4.6 (RESET); also elsewhere on the board
SPI_MISO: TP57.1, U3.7 (MISO), U4.2 (MISO); also elsewhere on the board
SPI_MOSI: TP58.1, U3.6 (MOSI), U4.3 (MOSI); also elsewhere on the board
SPI_SCK: TP59.1, U3.5 (SCK), U4.4 (SCK); also elsewhere on the board
SWITCHED_RADIO_POWER: C7.1, J5.2, Q1.3 (D), R7.2, TP48.1, U3.1 (VDD), U4.13 (3.3V)

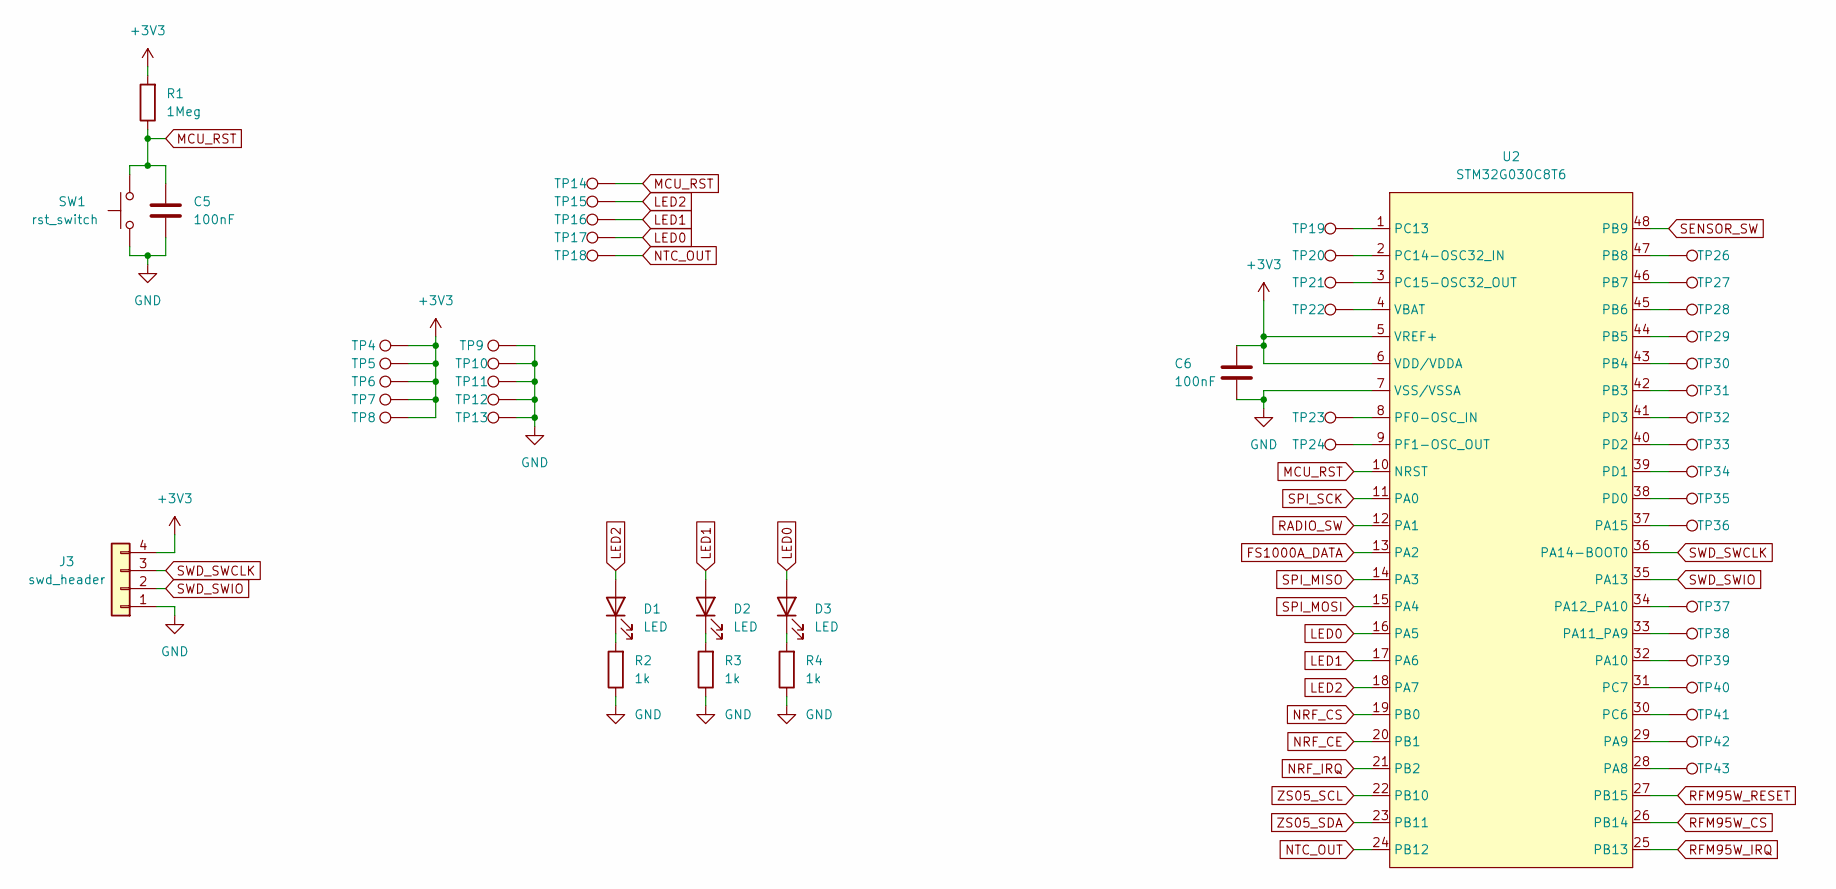
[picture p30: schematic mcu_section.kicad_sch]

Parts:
C5, C6: 100nF; C_0805_2012Metric
D1, D2, D3: LED; LED_1206_3216Metric
J3: swd_header; Conn_01x04
R1: 1Meg; R_0805_2012Metric
R2, R3, R4: 1k; R_0805_2012Metric
SW1: rst_switch; SW_SPST_TL3342
TP4, TP5, TP6, TP7, TP8, TP9, TP10, TP11, TP12, TP13, TP14, TP15, TP16, TP17, TP18, TP19, TP20, TP21, TP22, TP23, TP24, TP26, TP27, TP28, TP29, TP30, TP31, TP32, TP33, TP34, TP35, TP36, TP37, TP38, TP39, TP40, TP41, TP42, TP43: TestPoint; TestPoint_Pad_D1.0mm
U2: STM32G030C8T6; LQFP-48_7x7mm_P0.5mm

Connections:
+3V3: C6.1, J3.4, R1.2, TP4.1, TP5.1, TP6.1, TP7.1, TP8.1, U2.5 (VREF+), U2.6 (VDD/VDDA); also elsewhere on the board
FS1000A_DATA: U2.13 (PA2); also elsewhere on the board
GND: C5.1, C6.2, J3.1, R2.1, R3.1, R4.1, SW1.1, TP9.1, TP10.1, TP11.1, TP12.1, TP13.1, U2.7 (VSS/VSSA); also elsewhere on the board
LED0: D3.2 (A), TP17.1, U2.16 (PA5)
LED1: D2.2 (A), TP16.1, U2.17 (PA6)
LED2: D1.2 (A), TP15.1, U2.18 (PA7)
MCU_RST: C5.2, R1.1, SW1.2, TP14.1, U2.10 (NRST)
NRF_CE: U2.20 (PB1); also elsewhere on the board
NRF_CS: U2.19 (PB0); also elsewhere on the board
NRF_IRQ: U2.21 (PB2); also elsewhere on the board
NTC_OUT: TP18.1, U2.24 (PB12); also elsewhere on the board
unnamed: D1.1 (K), R2.2
unnamed: D2.1 (K), R3.2
unnamed: D3.1 (K), R4.2
unnamed: TP19.1, U2.1 (PC13)
unnamed: TP20.1, U2.2 (PC14-OSC32_IN)
unnamed: TP21.1, U2.3 (PC15-OSC32_OUT)
unnamed: TP22.1, U2.4 (VBAT)
unnamed: TP23.1, U2.8 (PF0-OSC_IN)
unnamed: TP24.1, U2.9 (PF1-OSC_OUT)
unnamed: TP26.1, U2.47 (PB8)
unnamed: TP27.1, U2.46 (PB7)
unnamed: TP28.1, U2.45 (PB6)
unnamed: TP29.1, U2.44 (PB5)
unnamed: TP30.1, U2.43 (PB4)
unnamed: TP31.1, U2.42 (PB3)
unnamed: TP32.1, U2.41 (PD3)
unnamed: TP33.1, U2.40 (PD2)
unnamed: TP34.1, U2.39 (PD1)
unnamed: TP35.1, U2.38 (PD0)
unnamed: TP36.1, U2.37 (PA15)
unnamed: TP37.1, U2.34 (PA12_PA10)
unnamed: TP38.1, U2.33 (PA11_PA9)
unnamed: TP39.1, U2.32 (PA10)
unnamed: TP40.1, U2.31 (PC7)
unnamed: TP41.1, U2.30 (PC6)
unnamed: TP42.1, U2.29 (PA9)
unnamed: TP43.1, U2.28 (PA8)
RADIO_SW: U2.12 (PA1); also elsewhere on the board
RFM95W_CS: U2.26 (PB14); also elsewhere on the board
RFM95W_IRQ: U2.25 (PB13); also elsewhere on the board
RFM95W_RESET: U2.27 (PB15); also elsewhere on the board
SENSOR_SW: U2.48 (PB9); also elsewhere on the board
SPI_MISO: U2.14 (PA3); also elsewhere on the board
SPI_MOSI: U2.15 (PA4); also elsewhere on the board
SPI_SCK: U2.11 (PA0); also elsewhere on the board
SWD_SWCLK: J3.3, U2.36 (PA14-BOOT0)
SWD_SWIO: J3.2, U2.35 (PA13)
ZS05_SCL: U2.22 (PB10); also elsewhere on the board
ZS05_SDA: U2.23 (PB11); also elsewhere on the board

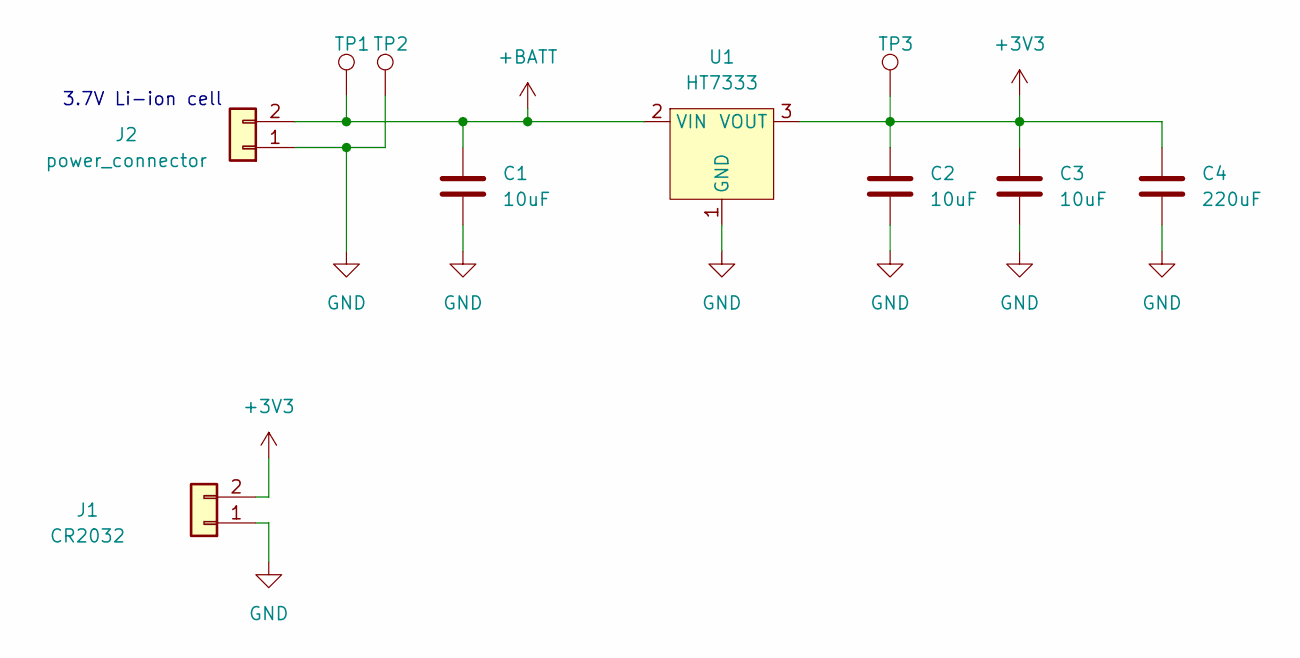
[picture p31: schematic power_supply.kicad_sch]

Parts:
C1, C2, C3: 10uF; C_0805_2012Metric
C4: 220uF; C_Radial_D6.3mm_H11.0mm_P2.50mm
J1: CR2032; CR2032_THT
J2: power_connector; PinHeader_1x02_P2.54mm_Vertical
TP1, TP2, TP3: TestPoint; TestPoint_Pad_D1.0mm
U1: HT7333; SOT-89-3

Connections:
+3V3: C2.1, C3.1, C4.1, J1.2, TP3.1, U1.3 (VOUT); also elsewhere on the board
+BATT: C1.1, J2.2, TP1.1, U1.2 (VIN)
GND: C1.2, C2.2, C3.2, C4.2, J1.1, J2.1, TP2.1, U1.1 (GND); also elsewhere on the board

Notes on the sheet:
3.7V Li-ion cell

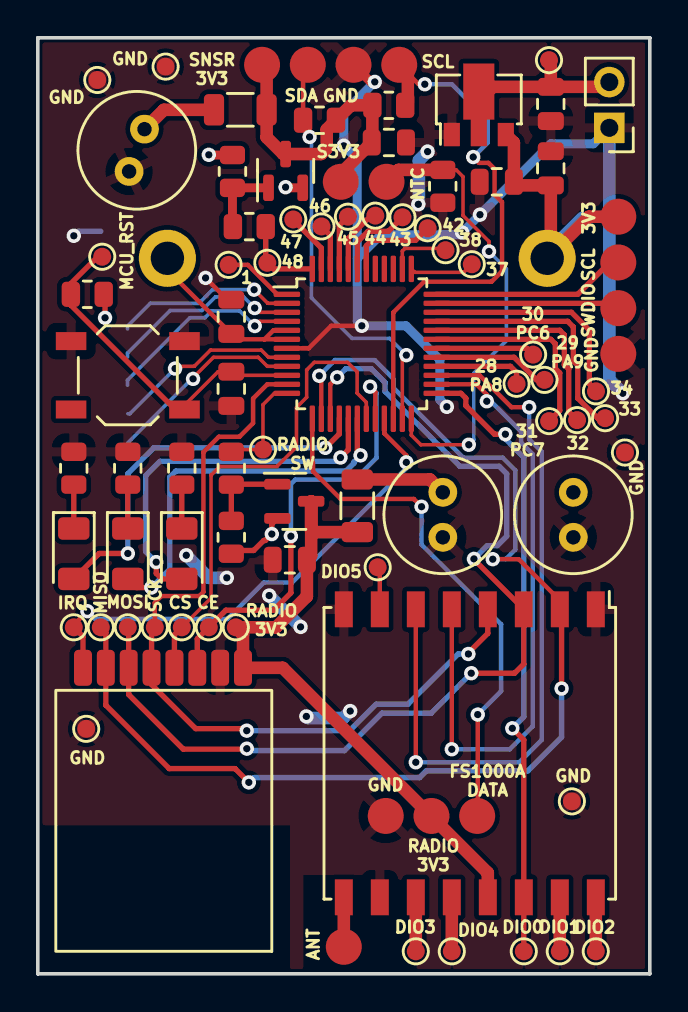
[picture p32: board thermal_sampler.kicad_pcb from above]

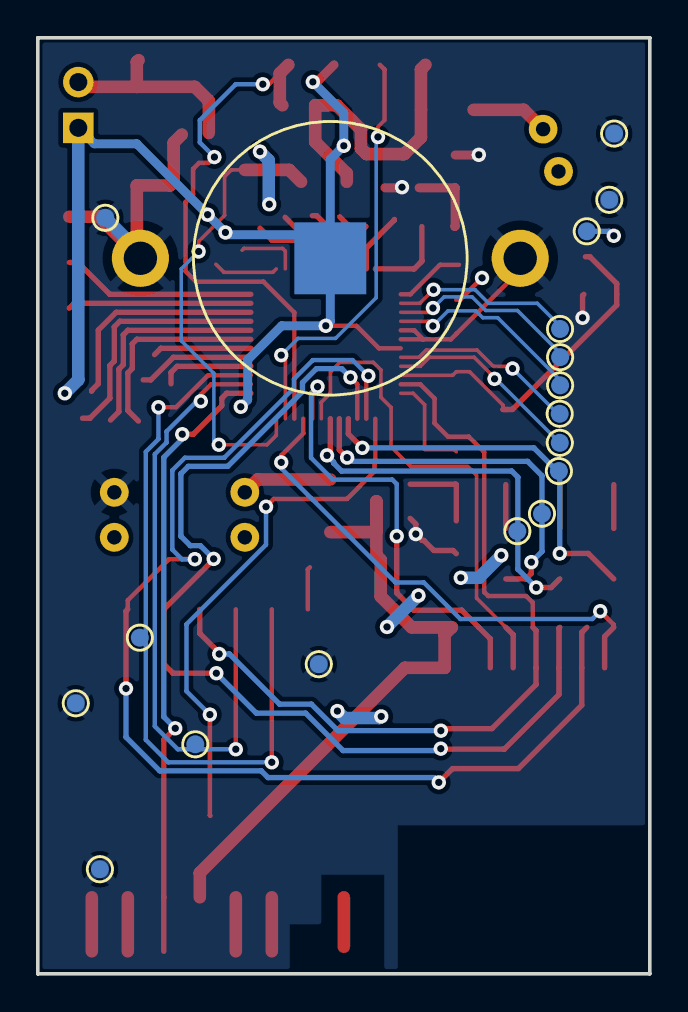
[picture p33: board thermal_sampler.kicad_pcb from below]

Board: 2 copper layers, 34.0 x 52.0 mm, 95 parts (18 on the bottom side), 60 nets.

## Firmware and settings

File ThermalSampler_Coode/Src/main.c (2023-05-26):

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
/* Includes ------------------------------------------------------------------*/
#include "main.h"

/* USER CODE BEGIN Includes */
#include "string.h"
#include "stdlib.h"
#include "nrf_driver.h"
// #include "ZS05.h"
#include "AH10.h"
/* USER CODE END Includes */

/* USER CODE BEGIN PTD */
typedef struct
{
  uint64_t device_address;
  int8_t temperature;
  uint8_t humidity;
  uint16_t battery_voltage;
} DataPacket;
/* USER CODE END PTD */

/* USER CODE BEGIN PD */
#define ZERO_ARRAY \
  {                \
    0,             \
  }
#define UNIQUE_ID_SEED __TIME__
/* USER CODE END PD */

/* USER CODE BEGIN PM */
uint64_t pseudorandom_id_generator(uint8_t *seed, int len)
{
  uint64_t x = 0;
  for (int i = 0; i < len; i++)
  {
    x ^= (uint64_t)seed[i] << (8 * (i % 8));
  }
  uint64_t x1 = 123456789, x2 = 362436069, x3 = 521288629, x4 = 88675123;
  for (int i = 0; i < 10; i++)
  {
    uint64_t t = x1 ^ (x1 << 11);
    x1 = x2;
    x2 = x3;
    x3 = x4;
    x4 = x4 ^ (x4 >> 19) ^ (t ^ (t >> 8));
  }
  x ^= x1;
  return x;
}
/* USER CODE END PM */

ADC_HandleTypeDef hadc1;
DMA_HandleTypeDef hdma_adc1;

I2C_HandleTypeDef hi2c2;

RTC_HandleTypeDef hrtc;

SPI_HandleTypeDef hspi2;

TIM_HandleTypeDef htim3;

UART_HandleTypeDef huart2;

/* USER CODE BEGIN PV */
uint8_t interrupt_got = 0;
/* USER CODE END PV */

void SystemClock_Config(void);
static void MX_GPIO_Init(void);
static void MX_DMA_Init(void);
static void MX_SPI2_Init(void);
static void MX_USART2_UART_Init(void);
static void MX_RTC_Init(void);
static void MX_ADC1_Init(void);
static void MX_TIM3_Init(void);
static void MX_I2C2_Init(void);
/* USER CODE BEGIN 0 */
uint16_t temperature_c;
uint16_t vref;
uint16_t volts0;
uint16_t packet_number = 0;
uint8_t ctr = 0;
/* USER CODE END 0 */

/**
  * @brief  The application entry point.
  * @retval int
  */
int main(void)
{
  /* MCU Configuration--------------------------------------------------------*/

  /* Reset of all peripherals, Initializes the Flash interface and the Systick. */
  HAL_Init();

  /* Configure the system clock */
  SystemClock_Config();

  /* Initialize all configured peripherals */
  MX_GPIO_Init();
  // MX_DMA_Init();
  MX_SPI2_Init();
  // MX_USART2_UART_Init();
  MX_RTC_Init();
  MX_ADC1_Init();
  // MX_TIM3_Init();
  MX_I2C2_Init();
  /* USER CODE BEGIN 2 */
  uint16_t adc_data[3] = ZERO_ARRAY;
  /* USER CODE END 2 */

  /* Infinite loop */
  /* USER CODE BEGIN WHILE */
  if (HAL_GPIO_ReadPin(PROG_EN_GPIO_Port, PROG_EN_Pin) == 0)
  {
    while (1)
    {
      HAL_GPIO_WritePin(LED0_GPIO_Port, LED0_Pin, GPIO_PIN_SET);
      HAL_GPIO_WritePin(LED1_GPIO_Port, LED1_Pin, GPIO_PIN_SET);
      HAL_GPIO_WritePin(LED2_GPIO_Port, LED2_Pin, GPIO_PIN_SET);
      HAL_Delay(100);
      HAL_GPIO_WritePin(LED0_GPIO_Port, LED0_Pin, GPIO_PIN_RESET);
      HAL_GPIO_WritePin(LED1_GPIO_Port, LED1_Pin, GPIO_PIN_RESET);
      HAL_GPIO_WritePin(LED2_GPIO_Port, LED2_Pin, GPIO_PIN_RESET);
      HAL_Delay(100);
    }
  }

  // GPIO_InitTypeDef GPIO_InitStruct = {0};

  // while (1)
  // {
  //   GPIO_InitStruct.Pin = SENSOR_SW_Pin;
  //   GPIO_InitStruct.Mode = GPIO_MODE_OUTPUT_PP;
  //   GPIO_InitStruct.Pull = GPIO_NOPULL;
  //   HAL_GPIO_Init(SENSOR_SW_GPIO_Port, &GPIO_InitStruct);
  //   HAL_GPIO_WritePin(SENSOR_SW_GPIO_Port, SENSOR_SW_Pin, GPIO_PIN_RESET);
  //   HAL_Delay(2000);

  //   GPIO_InitStruct.Pin = SENSOR_SW_Pin;
  //   GPIO_InitStruct.Mode = GPIO_MODE_INPUT;
  //   GPIO_InitStruct.Pull = GPIO_PULLUP;
  //   HAL_GPIO_Init(SENSOR_SW_GPIO_Port, &GPIO_InitStruct);
  //   HAL_Delay(2000);
  // }

  const uint64_t unique_id = pseudorandom_id_generator((uint8_t *)UNIQUE_ID_SEED, strlen(UNIQUE_ID_SEED));
  while (1)
  {
    HAL_GPIO_WritePin(LED1_GPIO_Port, LED1_Pin, GPIO_PIN_SET);
    HAL_GPIO_WritePin(RADIO_SW_GPIO_Port, RADIO_SW_Pin, GPIO_PIN_RESET);
    HAL_GPIO_WritePin(SENSOR_SW_GPIO_Port, SENSOR_SW_Pin, GPIO_PIN_RESET);

    // HAL_ADC_Start_DMA(&hadc1, adc_data, 3);
    HAL_Delay(2000);
    HAL_GPIO_WritePin(LED1_GPIO_Port, LED1_Pin, GPIO_PIN_RESET);


    // ZS05_Data sensor_data = ZERO_ARRAY;
    HAL_StatusTypeDef err = HAL_ERROR;
    ctr = 0;
    // do
    // {
    //   err = ZS05_Get_Temperature(&sensor_data);
    //   HAL_Delay(500);
    // } while (err == HAL_ERROR && ctr++ < 10);

    HAL_GPIO_WritePin(SENSOR_SW_GPIO_Port, SENSOR_SW_Pin, GPIO_PIN_SET);

    // if (err == HAL_OK)
    // {
    // vref = __HAL_ADC_CALC_VREFANALOG_VOLTAGE(adc_data[1] / 16, ADC_RESOLUTION_12B);
    // temperature_c = __HAL_ADC_CALC_TEMPERATURE(vref, adc_data[0] / 16, ADC_RESOLUTION_12B);
    // volts0 = __HAL_ADC_CALC_DATA_TO_VOLTAGE(vref, adc_data[2] / 16, ADC_RESOLUTION_12B);

    DataPacket dataPacket = ZERO_ARRAY;
    dataPacket.device_address = (unique_id);
    dataPacket.temperature = (sensor_data.temperature != 0) ? (sensor_data.temperature) : (int8_t)temperature_c;
    dataPacket.humidity = sensor_data.humidity;
    dataPacket.battery_voltage = vref;

    NRF_Tx_Init();
    NRF_SetPayloadLength(sizeof(DataPacket), 0);
    // NRF_SetPayloadLength(16, 0);
    NRF_FlushTxBuffer();
    NRF_WriteTxBuffer((uint8_t *)&dataPacket, sizeof(DataPacket), 0);
    // NRF_WriteTxBuffer((uint8_t *)"hello world!@#$", 16, 0);
    interrupt_got = 0;
    NRF_Execute();
    while (!(interrupt_got))
    {
    };
    uint8_t reg_stat = NRF_ReadRegister(NRF_REG_STATUS);
    if (reg_stat & (1 << 5))
    {

      NRF_WriteRegister(NRF_REG_CONFIG, 0);
      HAL_GPIO_WritePin(LED2_GPIO_Port, LED2_Pin, GPIO_PIN_SET);
      HAL_Delay(10);
      HAL_GPIO_WritePin(LED2_GPIO_Port, LED2_Pin, GPIO_PIN_RESET);
    }
    // }
    HAL_GPIO_WritePin(RADIO_SW_GPIO_Port, RADIO_SW_Pin, GPIO_PIN_SET);
    HAL_SPI_MspDeInit(&hspi2);

    GPIO_InitTypeDef gp = ZERO_ARRAY;
    gp.Mode = GPIO_MODE_ANALOG;
    gp.Pull = GPIO_NOPULL;
    gp.Speed = GPIO_SPEED_FREQ_LOW;
    gp.Pin = GPIO_PIN_All;
    HAL_GPIO_Init(GPIOA, &gp);
    HAL_GPIO_Init(GPIOB, &gp);

    HAL_NVIC_DisableIRQ(NRF_IRQ_EXTI_IRQn);
    HAL_NVIC_DisableIRQ(EXTI4_15_IRQn);

    // HAL_PWREx_EnablePullUpPullDownConfig();
    // HAL_PWREx_EnableGPIOPullUp(PWR_GPIO_A, RADIO_SW_Pin);
    // HAL_PWREx_EnableGPIOPullUp(PWR_GPIO_B, SENSOR_SW_Pin);
    // HAL_PWREx_EnableGPIOPullDown(PWR_GPIO_A, (uint16_t)~RADIO_SW_Pin);
    // HAL_PWREx_EnableGPIOPullDown(PWR_GPIO_B, (uint16_t) ~(SENSOR_SW_Pin));

    // HAL_PWREx_EnableGPIOPullUp(RADIO_SW_GPIO_Port, RADIO_SW_Pin);
    // HAL_PWREx_EnableGPIOPullUp(SENSOR_SW_GPIO_Port, SENSOR_SW_Pin);
    // HAL_PWR_EnterSTOPMode(PWR_LOWPOWERREGULATOR_ON, PWR_STOPENTRY_WFI);
    HAL_PWR_DisableWakeUpPin(PWR_WAKEUP_PIN1);
    HAL_PWR_DisableWakeUpPin(PWR_WAKEUP_PIN2);
    HAL_PWR_DisableWakeUpPin(PWR_WAKEUP_PIN4);
    HAL_PWR_DisableWakeUpPin(PWR_WAKEUP_PIN6);

    __HAL_RTC_CALIBRATION_OUTPUT_DISABLE(&hrtc);
    __HAL_RTC_TAMPER_DISABLE(&hrtc, RTC_TAMPER_ALL);

    __HAL_RTC_WAKEUPTIMER_CLEAR_FLAG(&hrtc, RTC_FLAG_WUTF);
    __HAL_PWR_CLEAR_FLAG(PWR_FLAG_WUF);

    // __HAL_RCC_GPIOA_CLK_DISABLE();
    // __HAL_RCC_GPIOB_CLK_DISABLE();

    HAL_PWR_EnterSTANDBYMode();
    // HAL_Delay(1000);
    /* USER CODE END WHILE */

    /* USER CODE BEGIN 3 */
  }
  /* USER CODE END 3 */
}

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


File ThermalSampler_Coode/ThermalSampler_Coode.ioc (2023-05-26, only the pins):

Mcu.UserName=STM32G030C8Tx
PA0.Signal=SPI2_SCK
PA1.GPIO_Label=RADIO_SW
PA1.Signal=GPIO_Output
PA13.Signal=SYS_SWDIO
PA14-BOOT0.Signal=SYS_SWCLK
PA2.GPIO_Label=FS1000A_DATA
PA2.Signal=USART2_TX
PA3.Signal=SPI2_MISO
PA4.Signal=SPI2_MOSI
PA5.GPIO_Label=LED0
PA5.Signal=GPIO_Output
PA6.GPIO_Label=LED1
PA6.Signal=GPIO_Output
PA7.GPIO_Label=LED2
PA7.Signal=GPIO_Output
PB0.GPIO_Label=NRF_CS
PB0.Signal=GPIO_Output
PB1.GPIO_Label=NRF_CE
PB1.Signal=GPIO_Output
PB10.Signal=I2C2_SCL
PB11.Signal=I2C2_SDA
PB12.GPIO_Label=NTC_THERMISTOR
PB12.Signal=SharedAnalog_PB12
PB13.GPIO_Label=RFM95W_IRQ
PB13.Signal=GPXTI13
PB14.GPIO_Label=RFM95W_CS
PB14.Signal=GPIO_Output
PB15.GPIO_Label=RFM95W_RESET
PB15.Signal=GPIO_Output
PB2.GPIO_Label=NRF_IRQ
PB2.Signal=GPXTI2
PB9.GPIO_Label=SENSOR_SW
PB9.Signal=GPIO_Output

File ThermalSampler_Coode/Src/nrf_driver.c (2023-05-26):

#include "nrf_driver.h"

extern SPI_HandleTypeDef hspi2;
uint8_t buf[0x1c] = {0,};

void SPI_Transmit(uint8_t *data, uint32_t length_of_data);

void SPI_Transmit(uint8_t *data, uint32_t length_of_data)
{
	HAL_SPI_TransmitReceive(&hspi2, data, buf, length_of_data, 1000);
}

NRF24L01_Register_Map nrf_register_map = {
	0,
};

uint8_t NRF_ReadRegister(uint8_t register_addr)
{
	uint8_t byte_read = 0xFF;
	NRF_CS_LOW;
	SPI_Transmit((uint8_t[]){NRF_COMMAND_R_REGISTER | register_addr}, 1);
	HAL_SPI_Receive(&hspi2, &byte_read, 1, 100);
	NRF_CS_HIGH;


	return byte_read;
}

void NRF_WriteRegister(uint8_t register_addr, uint8_t data_to_write)
{
	NRF_CS_LOW;
	SPI_Transmit((uint8_t[]){NRF_COMMAND_W_REGISTER | register_addr, data_to_write}, 2);
	NRF_CS_HIGH;

}

void NRF_SetTxAddress(uint8_t *addr, uint8_t len)
{
	NRF_CS_LOW;
	SPI_Transmit((uint8_t[]){NRF_COMMAND_W_REGISTER | NRF_REG_TX_ADDR}, 1);
	SPI_Transmit(addr, len);
	NRF_CS_HIGH;

}

void NRF_SetRxAddress(uint8_t *addr, uint8_t len)
{
	NRF_CS_LOW;
	SPI_Transmit((uint8_t[]){NRF_COMMAND_W_REGISTER | NRF_REG_RX_ADDR_P0}, 1);
	SPI_Transmit(addr, len);
	NRF_CS_HIGH;
}

void NRF_WriteTxBuffer(uint8_t *data, uint8_t len, uint8_t pipe)
{
	NRF_CS_LOW;
	SPI_Transmit((uint8_t[]){NRF_COMMAND_W_TX_PAYLOAD | pipe}, 1);
	SPI_Transmit(data, len);
	NRF_CS_HIGH;
}

void NRF_ReadRxBuffer(uint8_t *buffer, uint8_t len)
{
	NRF_CS_LOW;
	SPI_Transmit((uint8_t[]){NRF_COMMAND_R_RX_PAYLOAD}, 1);
	HAL_SPI_Receive(&hspi2, buffer, len, 100);
	NRF_CS_HIGH;
}

void NRF_FlushTxBuffer(void)
{
	NRF_CS_LOW;
	SPI_Transmit((uint8_t[]){NRF_COMMAND_FLUSH_TX}, 1);
	NRF_CS_HIGH;
}

void NRF_FlushRxBuffer(void)
{
	NRF_CS_LOW;
	SPI_Transmit((uint8_t[]){NRF_COMMAND_FLUSH_RX}, 1);
	NRF_CS_HIGH;
}

void NRF_Execute(void)
{
	NRF_CE_HIGH;
	NRF_DELAY(1);
	NRF_CE_LOW;
}

void NRF_Execute_Rx(void)
{
	NRF_CE_HIGH;
}

void NRF_Tx_Init(void)
{
	NRF_CS_HIGH;
	NRF_CE_LOW;


	//waking up
	while((NRF_ReadRegister(NRF_REG_CONFIG) & 0b10) != 0b10)
	{
		nrf_register_map.CONFIG.CONFIG_Byte = 0;		//setting byte as 0
		nrf_register_map.CONFIG.CONFIG_Bits.PWR_UP = 1; //powering up
		NRF_WriteRegister(NRF_REG_CONFIG, nrf_register_map.CONFIG.CONFIG_Byte);
	}


	nrf_register_map.CONFIG.CONFIG_Bits.CRCO = 0;		 //CRC 1 byte
	nrf_register_map.CONFIG.CONFIG_Bits.EN_CRC = 1;		 //disable CRC
	nrf_register_map.CONFIG.CONFIG_Bits.MASK_MAX_RT = 1; //do not IRQ on MAX_RT
	nrf_register_map.CONFIG.CONFIG_Bits.MASK_TX_DS = 0;	 //set IRQ on TX_DS
	nrf_register_map.CONFIG.CONFIG_Bits.MASK_RX_DR = 1;	 //do not IRQ on RX_DR
	nrf_register_map.CONFIG.CONFIG_Bits.PRIM_RX = 0;	 //set as TX
	NRF_WriteRegister(NRF_REG_CONFIG, nrf_register_map.CONFIG.CONFIG_Byte);
	

	//no auto ACK
	nrf_register_map.EN_AA.EN_AA_Byte = 0;
	NRF_WriteRegister(NRF_REG_EN_AA, nrf_register_map.EN_AA.EN_AA_Byte);

	//no RX enable
	nrf_register_map.EN_RXADDR.EN_RXADDR_Byte = 0;
	NRF_WriteRegister(NRF_REG_EN_RXADDR, nrf_register_map.EN_RXADDR.EN_RXADDR_Byte);

	//setting address width as 5 bytes
	nrf_register_map.SETUP_AW.SETUP_AW_Bits.AW = 3;
	NRF_WriteRegister(NRF_REG_SETUP_AW, nrf_register_map.SETUP_AW.SETUP_AW_Byte);

	//auto retransmission
	nrf_register_map.SETUP_RETR.SETUP_RETR_Byte = 0;
	NRF_WriteRegister(NRF_REG_SETUP_RETR, nrf_register_map.SETUP_RETR.SETUP_RETR_Byte);

	//setting channel
	nrf_register_map.RF_CH.RF_CH_Bits.RF_CH = 2; //3rd channel
	NRF_WriteRegister(NRF_REG_RF_CH, nrf_register_map.RF_CH.RF_CH_Byte);

	//enabling LNA, Tx power, air data rate
	nrf_register_map.RF_SETUP.RF_SETUP_Bits.DONT_CARE = 1;
	nrf_register_map.RF_SETUP.RF_SETUP_Bits.CONT_WAVE = 0;
	nrf_register_map.RF_SETUP.RF_SETUP_Bits.RF_DR_LOW = 1;
	nrf_register_map.RF_SETUP.RF_SETUP_Bits.PLL_LOCK = 0;
	nrf_register_map.RF_SETUP.RF_SETUP_Bits.RF_DR_HIGH = 0;
	nrf_register_map.RF_SETUP.RF_SETUP_Bits.RF_PWR = 0b11;
	NRF_WriteRegister(NRF_REG_RF_SETUP, nrf_register_map.RF_SETUP.RF_SETUP_Byte);

	//setting address
	nrf_register_map.TX_ADDR[0] = 0x12;
	nrf_register_map.TX_ADDR[1] = 0x34;
	nrf_register_map.TX_ADDR[2] = 0x56;
	nrf_register_map.TX_ADDR[3] = 0x78;
	nrf_register_map.TX_ADDR[4] = 0x9A;
	NRF_SetTxAddress(nrf_register_map.TX_ADDR, 5);

	//no dynamic payload length
	nrf_register_map.DYNPD.DYNPD_Byte = 0;
	NRF_WriteRegister(NRF_REG_DYNPD, nrf_register_map.DYNPD.DYNPD_Byte);

	nrf_register_map.FEATURE.FEATURE_Byte = 0;
	NRF_WriteRegister(NRF_REG_FEATURE, nrf_register_map.FEATURE.FEATURE_Byte);
}

void NRF_Rx_Init(void)
{
	NRF_CS_HIGH;
	NRF_CE_LOW;

	//waking up
	nrf_register_map.CONFIG.CONFIG_Byte = 0;		//setting byte as 0
	nrf_register_map.CONFIG.CONFIG_Bits.PWR_UP = 1; //powering up
	NRF_WriteRegister(NRF_REG_CONFIG, nrf_register_map.CONFIG.CONFIG_Byte);
	NRF_DELAY(20);										 //wakeup delay 20ms
	
	nrf_register_map.CONFIG.CONFIG_Bits.CRCO = 0;		 //CRC 1 byte
	nrf_register_map.CONFIG.CONFIG_Bits.EN_CRC = 1;		 //disable CRC
	nrf_register_map.CONFIG.CONFIG_Bits.MASK_MAX_RT = 1; //do not set IRQ on MAX_RT
	nrf_register_map.CONFIG.CONFIG_Bits.MASK_TX_DS = 1;	 //do not set IRQ on TX_DS
	nrf_register_map.CONFIG.CONFIG_Bits.MASK_RX_DR = 0;	 //set IRQ on RX_DR
	nrf_register_map.CONFIG.CONFIG_Bits.PRIM_RX = 1;	 //set as RX
	NRF_WriteRegister(NRF_REG_CONFIG, nrf_register_map.CONFIG.CONFIG_Byte);

	//no auto ACK
	nrf_register_map.EN_AA.EN_AA_Byte = 0;
	NRF_WriteRegister(NRF_REG_EN_AA, nrf_register_map.EN_AA.EN_AA_Byte);

	//no RX enable
	nrf_register_map.EN_RXADDR.EN_RXADDR_Bits.ERX_P0 = 1;
	NRF_WriteRegister(NRF_REG_EN_RXADDR, nrf_register_map.EN_RXADDR.EN_RXADDR_Byte);

	//setting address width as 5 bytes
	nrf_register_map.SETUP_AW.SETUP_AW_Bits.AW = 3;
	NRF_WriteRegister(NRF_REG_SETUP_AW, nrf_register_map.SETUP_AW.SETUP_AW_Byte);

	//auto retransmission
	nrf_register_map.SETUP_RETR.SETUP_RETR_Byte = 0;
	NRF_WriteRegister(NRF_REG_SETUP_RETR, nrf_register_map.SETUP_RETR.SETUP_RETR_Byte);

	//setting channel
	nrf_register_map.RF_CH.RF_CH_Bits.RF_CH = 2; //3rd channel
	NRF_WriteRegister(NRF_REG_RF_CH, nrf_register_map.RF_CH.RF_CH_Byte);

	//enabling LNA, Tx power, air data rate
	nrf_register_map.RF_SETUP.RF_SETUP_Bits.DONT_CARE = 1;
	nrf_register_map.RF_SETUP.RF_SETUP_Bits.CONT_WAVE = 0;
	nrf_register_map.RF_SETUP.RF_SETUP_Bits.RF_DR_LOW = 1;
	nrf_register_map.RF_SETUP.RF_SETUP_Bits.PLL_LOCK = 0;
	nrf_register_map.RF_SETUP.RF_SETUP_Bits.RF_DR_HIGH = 0;
	nrf_register_map.RF_SETUP.RF_SETUP_Bits.RF_PWR = 0b11;
	NRF_WriteRegister(NRF_REG_RF_SETUP, nrf_register_map.RF_SETUP.RF_SETUP_Byte);

	//setting address
	nrf_register_map.RX_ADDR_P0[0] = 0x12;
	nrf_register_map.RX_ADDR_P0[1] = 0x34;
	nrf_register_map.RX_ADDR_P0[2] = 0x56;
	nrf_register_map.RX_ADDR_P0[3] = 0x78;
	nrf_register_map.RX_ADDR_P0[4] = 0x9A;
	NRF_SetRxAddress(nrf_register_map.RX_ADDR_P0, 5);

	//payload length
	nrf_register_map.RX_PW_P0.RX_PW_P0_Bits.RX_PW_P0 = 0;
	NRF_WriteRegister(NRF_REG_RX_PW_P0, nrf_register_map.RX_PW_P0.RX_PW_P0_Byte);

	//no dynamic payload length
	nrf_register_map.DYNPD.DYNPD_Byte = 0;
	NRF_WriteRegister(NRF_REG_DYNPD, nrf_register_map.DYNPD.DYNPD_Byte);
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

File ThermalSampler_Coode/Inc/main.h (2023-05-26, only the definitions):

#define RADIO_SW_Pin GPIO_PIN_1
#define RADIO_SW_GPIO_Port GPIOA
#define FS1000A_DATA_Pin GPIO_PIN_2
#define FS1000A_DATA_GPIO_Port GPIOA
#define LED0_Pin GPIO_PIN_5
#define LED0_GPIO_Port GPIOA
#define LED1_Pin GPIO_PIN_6
#define LED1_GPIO_Port GPIOA
#define LED2_Pin GPIO_PIN_7
#define LED2_GPIO_Port GPIOA
#define NRF_CS_Pin GPIO_PIN_0
#define NRF_CS_GPIO_Port GPIOB
#define NRF_CE_Pin GPIO_PIN_1
#define NRF_CE_GPIO_Port GPIOB
#define NRF_IRQ_Pin GPIO_PIN_2
#define NRF_IRQ_GPIO_Port GPIOB
#define NRF_IRQ_EXTI_IRQn EXTI2_3_IRQn
#define NTC_THERMISTOR_Pin GPIO_PIN_12
#define NTC_THERMISTOR_GPIO_Port GPIOB
#define RFM95W_IRQ_Pin GPIO_PIN_13
#define RFM95W_IRQ_GPIO_Port GPIOB
#define RFM95W_IRQ_EXTI_IRQn EXTI4_15_IRQn
#define RFM95W_CS_Pin GPIO_PIN_14
#define RFM95W_CS_GPIO_Port GPIOB
#define RFM95W_RESET_Pin GPIO_PIN_15
#define RFM95W_RESET_GPIO_Port GPIOB
#define PROG_EN_Pin GPIO_PIN_12
#define PROG_EN_GPIO_Port GPIOA
#define SENSOR_SW_Pin GPIO_PIN_9
#define SENSOR_SW_GPIO_Port GPIOB

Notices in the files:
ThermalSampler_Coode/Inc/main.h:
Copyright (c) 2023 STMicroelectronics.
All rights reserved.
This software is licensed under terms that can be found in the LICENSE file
